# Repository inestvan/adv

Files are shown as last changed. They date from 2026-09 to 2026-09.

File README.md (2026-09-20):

# ADV7280M-CSI2 — CVBS → MIPI CSI-2 декодер для Raspberry Pi 4

Плата на Analog Devices **ADV7280WBCPZ-M** (LFCSP-32): композитный видеосигнал (PAL/NTSC/SECAM, разъём RCA)
преобразуется в поток MIPI CSI-2 (1 лента + клок) и подаётся на разъём камеры Raspberry Pi 4.
В той же заготовке — **отделяемая секция с буфером THS7314**: один вход CVBS раздаётся на декодер и два монитора
(питание секции 5 В от внешнего DC-DC через винтовую клемму).
Работает со штатным overlay ядра Raspberry Pi без правок:

```
dtoverlay=adv728x-m,adv7280m=1
```

Проект сделан в KiCad 9 (`hw/`), плата 4 слоя **42 × 55 мм** (декодер 42 × 32 + паз 2 мм + секция буфера 42 × 21) под стек JLCPCB JLC04161H-7628.
ERC и DRC — 0 ошибок, 0 предупреждений. Все решения и допущения по этапам — в `docs/assumptions.md`,
исходные требования и выжимка из документации — в `docs/requirements.md`.

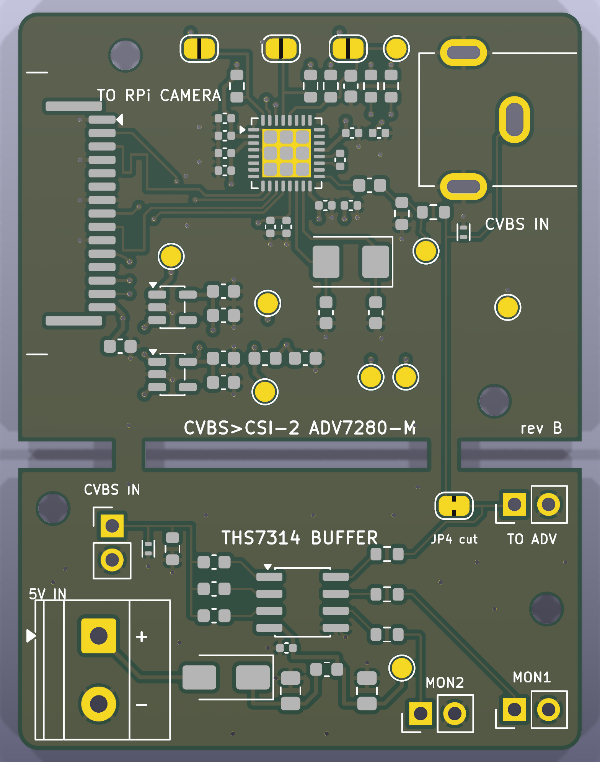
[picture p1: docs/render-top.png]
top


## Состав репозитория

| Путь | Что |
|---|---|
| `hw/adv7280m-csi2.kicad_pro / .kicad_sch / .kicad_pcb` | проект KiCad 9 |
| `hw/lib/` | символы ADV7280WBCPZ-M и THS7314, символы питания, посадочные места FFC (Amphenol SFW15R-1STE1LF), RCA (PSG01546), X1SON |
| `docs/schematic.pdf`, `docs/bom.csv` | схема и BOM с кодами LCSC |
| `docs/render-top.png`, `docs/render-bottom.png`, `docs/layer-*.png` | 3D-рендеры и медь по слоям |
| `docs/datasheets/`, `docs/ref/` | даташит ADV7280 Rev. A, UG-637 Rev. A, AN-1260, THS7314 (SLOS513A), схемы Pi 4 и Camera Module v2.1, overlay/драйвер из ядра Pi |
| `fab/adv7280m-csi2-gerber.zip` | Gerber (RS-274X, Protel-расширения) + Excellon drill + gbrjob со стеком |
| `fab/BOM_JLCPCB.csv`, `fab/CPL_JLCPCB.csv` | BOM и позиции в формате JLCPCB (только то, что собирает JLCPCB) |
| `tools/` | генераторы: `gen_lib.py` → `gen_fp.py` → `gen_sch.py` → `gen_pcb.py` → `route_pcb.py` → `write_pro.py`; `check_nets.py` проверяет нетлист; `fab.sh` делает Gerber/BOM/CPL, `render.sh` — картинки |

Пересборка с нуля:

```
python3 tools/gen_lib.py && python3 tools/gen_fp.py && python3 tools/gen_sch.py && python3 tools/check_nets.py
cd hw && kicad-cli sch export netlist --format kicadxml -o adv7280m-csi2.xml adv7280m-csi2.kicad_sch && cd ..
python3 tools/gen_pcb.py && python3 tools/route_pcb.py && python3 tools/write_pro.py
sh tools/fab.sh          # Gerber, drill, BOM/CPL JLCPCB, schematic.pdf, bom.csv
```

## Схема в двух словах

* **Вход**: RCA J2 → ESD TPD1E10B06 → 22 Ω последовательно, 51 Ω на землю (терминация 73 Ω, делитель 0,7) → 100 нФ → AIN1.
* **Питание**: 3,3 В с пина 15 разъёма камеры. Два LDO AP2112K-1.8: U2 → DVDD+MVDD, U3 → AVDD, PVDD через феррит.
  У каждого вывода питания чипа 100 нФ + 10 нФ.
* **Кварц** 28.63636 МГц (YXC 5032, CL 20 пФ), нагрузочные 27 пФ.
* **MIPI**: D0P/D0N → пины 3/2 разъёма, CLKP/CLKN → пины 9/8; лента 1 не используется. Дифпары 100 Ω (0,18/0,15 мм),
  длины выровнены до 0,04 мм в паре и 0,03 мм между парами.
* **I²C**: SDA/SCL → пины 14/13, подтяжки 4,7 кОм (параллельно подтяжкам Pi). ALSB = 1 → 7-битный адрес **0x21**
  (8-битный 0x42 write / 0x43 read) — ровно то, что ждёт overlay.
* **RESET**: 10 кОм + 4,7 мкФ (τ ≈ 47 мс, низкий уровень ≥ 13 мс), **PWRDWN**: 10 кОм к 3,3 В — чип запускается сам, без участия Pi.

### Секция буфера THS7314 (отделяемая)

* **Вход** J5 (штырьки 2,54 мм: 1 = сигнал, 2 = GND) → терминация 75 Ω, ESD → 3 × 100 нФ → три канала THS7314 (усиление 6 дБ, ФНЧ 8,5 МГц, sync-tip clamp).
* **Выходы** с 75 Ω последовательно (на нагрузке 75 Ω уровень 1 : 1): канал 1 → узел входа декодера (через JP4 и дорожку через перешеек),
  каналы 2 и 3 → J6 «MON1» и J7 «MON2» (штырьки, 1 = сигнал, 2 = GND) на мониторы. J8 «TO ADV» — тот же сигнал канала 1
  для случая, когда секция отломана: соединить кабелем с RCA J2.
* **Питание** J4 (винтовая клемма 5,08 мм, «+» = 5 В, «−» = GND) от внешнего DC-DC 5 В → диод SS14 (защита от переполюсовки)
  → 22 мкФ → феррит → 10 мкФ + 100 нФ. THS7314 работает от 3 до 5 В, LDO не нужен; потребление ≈ 17 мА. Тестовая точка TP9.
* **Декодер питается от Pi** (3,3 В по шлейфу камеры), клемма 5 В его не питает. Pi подключают к тому же 5 В своим кабелем.
* **Разделение**: паз 2 мм и два перешейка 2,5 мм (x = 7…9,5 и 30,5…33 мм). Через перешейки идут только CVBS_IN и земля.
  Перекусить кусачками, края зачистить. После отделения декодер 42 × 32 мм, буфер 42 × 21 мм, у каждого свои отверстия M2.

### Перемычки (паяльные, по умолчанию разомкнуты)

| | Замкнуть, если |
|---|---|
| JP1 `ALSB>GND` | нужен адрес 0x20; тогда в config.txt `dtoverlay=adv728x-m,adv7280m=1,addr=0x20` |
| JP2 `CAM_GPIO>RST` | хотите сбрасывать чип линией CAM_GPIO (пин 11 разъёма). Штатный overlay эту линию не включает, поэтому по умолчанию разомкнуто |
| JP3 `CAM_GPIO>PWRDWN` | хотите усыплять чип линией CAM_GPIO. То же самое: только со своим overlay, где включён регулятор `cam1_reg` |
| JP4 `BUF>ADV` (**замкнута** с завода) | **разрезать**, если платы соединены, а сигнал нужно подать прямо в RCA J2 минуя буфер: иначе выход буфера шунтирует вход |

### Тестовые точки

TP1 3V3 · TP2 1V8D · TP8 1V8A · TP3 SDA · TP4 SCL · TP5 RESET · TP6 GND · TP7 CVBS после терминации (сюда должно приходить ≈0,7 В p-p при 1 В на входе) · TP9 питание THS7314 (≈4,6 В).

## Подключение к Raspberry Pi 4

1. Стандартный 15-жильный шлейф камеры Pi (тот же, что у Camera Module). На плате разъём такой же, как на модуле камеры:
   контакты шлейфа **к плате**, синяя сторона к защёлке. Пин 1 (GND) помечен треугольником, он у верхнего края.
   На Pi 4: контакты шлейфа в сторону HDMI, синяя сторона к Ethernet/USB.
2. Перед первым включением прозвоните: пин 15 шлейфа (3,3 В) ↔ TP1, пин 1 ↔ TP6 (GND).
3. В `/boot/firmware/config.txt` (на старых образах `/boot/config.txt`):

   ```
   camera_auto_detect=0
   dtoverlay=adv728x-m,adv7280m=1
   ```

   Строка `camera_auto_detect=0` отключает автопоиск камер Pi, который иначе может занять I²C и CSI.
4. Перезагрузка и проверка:

   ```
   dmesg | grep -i adv7180          # ожидается: adv7180 10-0021: chip found @ 0x21 ... (шина i2c-10 на Pi 4)
   v4l2-ctl --list-devices          # unicam -> /dev/video0
   v4l2-ctl -d /dev/video0 --get-detected-standard
   v4l2-ctl -d /dev/video0 --set-standard=PAL     # или NTSC
   ```

   Драйвер `adv7180` работает как V4L2 subdevice за `bcm2835-unicam` (в overlay по умолчанию legacy-режим,
   Media Controller выключен). Формат на выходе — 8-битный YUV 4:2:2 (UYVY), 720×576 (PAL) или 720×480 (NTSC), чересстрочный.
5. Захват:

   ```
   v4l2-ctl -d /dev/video0 --set-fmt-video=width=720,height=576,pixelformat=UYVY --stream-mmap --stream-count=100 --stream-to=out.uyvy
   ffmpeg -f v4l2 -input_format uyvy422 -video_size 720x576 -i /dev/video0 -c:v libx264 -preset veryfast out.mkv
   ```

### Вывод на ПК как «карта захвата»

Плата отдаёт только MIPI CSI-2, напрямую к ПК её не подключить. Варианты через Pi 4:

* **UVC-вебкамера по USB-C.** Pi 4 умеет режим USB-устройства: `dtoverlay=dwc2` в config.txt, модуль `libcomposite`,
  и `uvc-gadget` (github.com/raspberrypi/uvc-gadget или kbingham/uvc-gadget с источником V4L2 `/dev/video0`).
  ПК видит обычную вебкамеру 720×576. Не проверялось на этой плате, но это штатный механизм Pi.
* **Поток по сети**: `ffmpeg -f v4l2 -i /dev/video0 ... -f mpegts udp://ПК:5000` или GStreamer/RTSP; на ПК VLC/OBS/ffplay.

## Заказ и сборка на JLCPCB

1. Плата: загрузить `fab/adv7280m-csi2-gerber.zip`. Параметры: 4 слоя, 1,6 мм, стек **JLC04161H-7628**
   (файл `.gbrjob` содержит стек), «Impedance control: yes» (пары 100 Ω дифф, 0,18/0,15 мм), остальное по умолчанию.
   Паз между секциями и перешейки лежат в контуре платы (Edge.Cuts) — это одна плата, опции панелизации/V-cut не нужны.
2. Сборка: Economic (SMT), верхняя сторона. Загрузить `fab/BOM_JLCPCB.csv` и `fab/CPL_JLCPCB.csv`.
   **В предпросмотре обязательно сверить ориентацию** полярных деталей: U2/U3 (SOT-23-5, пин 1 у метки-треугольника),
   D1/D3 (ESD, двунаправленные — ориентация не важна), J1 (FFC: контакты к краю платы, пин 1 сверху), Y1 (кварц — не важна),
   U5 (SOIC-8, пин 1 слева сверху, у метки), D2 (SS14: катодная полоска к C28, т. е. вправо).
   JLCPCB иногда поворачивает корпуса относительно данных KiCad; в предпросмотре это видно по картинке детали.
3. Не собирает JLCPCB (припаять самостоятельно): **U1 ADV7280WBCPZ-M** (нет на складе; фен + трафарет, паста на термопад ≈50 %),
   **J2** RCA-гнездо (любое угловое 3-выводное с штырём 1,3×2,5 и ушками 2,5×1 на 10 мм, например Multicomp PSG01546),
   **J4** винтовая клемма 2 конт. шаг 5,0/5,08 мм (KF301-5.0-2P, LCSC C474881; ставить вводом проводов к кромке),
   **J5–J8** штырьки 1×2 2,54 мм (PZ254V-11-02P, C492401 или любые); перемычки/тестовые точки — это просто площадки.
   THT-сборку у JLCPCB не заказываем — это дешевле, чем доплата за выводной монтаж.
4. Трафарет: заказать вместе с платой («Stencil», верхняя сторона) — он нужен для чипа; паста на термопад уже разбита на 4 окна.

Extended-позиции (по 3 $ за наименование): LDO, кварц, 27 пФ, ESD-диод, FFC-разъём, THS7314. Остальное (21 строка BOM, 48 деталей всего) — Basic.

## Известные особенности

* В каждой дифпаре MIPI линия N делает один переход на нижний слой и обратно (два via 0,45/0,2 мм): порядок P/N на
  разъёме Pi обратен порядку выводов чипа, без перекрёстка это не разводится (см. `docs/assumptions.md`, A3-2).
* 22 Ω вместо 24 Ω в терминации — 24 Ω нет в базовой библиотеке JLCPCB; коэффициент делителя 0,70 вместо 0,68 (+3 % амплитуды), АРУ декодера это компенсирует.
* Пока платы соединены, вход декодера занят буфером: RCA J2 использовать только после разреза JP4.
* Земля Pi и платы замкнута дважды (шлейф камеры и общее питание 5 В). Для CVBS это не критично; при помехах питать Pi и DC-DC от одной точки короткими проводами.
* DC-DC выставить на 5,0 В **до** подключения: абсолютный максимум THS7314 — 5,5 В.

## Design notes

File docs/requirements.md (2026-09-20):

# Требования к плате CVBS → MIPI CSI-2 (ADV7280WBCPZ-M) для Raspberry Pi 4

Этап 0. Выжимка из первоисточников. Всё, что ниже, взято из документов в `docs/datasheets/` и `docs/ref/`;
номера страниц/таблиц указаны по этим файлам.

## 0. Источники

| Файл | Документ | Ревизия | MD5 |
|---|---|---|---|
| `docs/datasheets/ADV7280.pdf` | ADV7280/ADV7280-M Data Sheet | Rev. A (2/2014), 28 стр. | `108880c7c29a0bb6fe3f480b3ebaaed1` |
| `docs/datasheets/UG-637.pdf` | ADV7280/7281/7282/7283 Hardware Reference Manual UG-637 | Rev. A (9/2014), 104 стр. | `9c16c44524c335801548c131bd12a8ec` |
| `docs/datasheets/AN-1260.pdf` | AN-1260 Crystal Design Considerations for Video Decoders… | Rev. 0, 4 стр. | `b3181a87c3ffb049ff7fd0b43f3015a6` |
| `docs/ref/rpi4-reduced-schematics.pdf` | Raspberry Pi 4 Model B Reduced Schematics (datasheets.raspberrypi.com) | 2018 | — |
| `docs/ref/rpi-camera-v2-schematic.pdf` | Raspberry Pi Camera V2.1 schematic (datasheets.raspberrypi.com) | 2.1 | — |
| `docs/ref/adv7282m-overlay.dts`, `adv728x-m-overlay.dts` | raspberrypi/linux, ветка `rpi-6.12.y`, `arch/arm/boot/dts/overlays/` | — | — |
| `docs/ref/adv7180.c`, `adv7180.yaml` | драйвер и DT-binding, та же ветка | — | — |
| `docs/ref/bcm2711-rpi-4-b.dts`, `bcm2711-rpi.dtsi`, `bcm270x.dtsi`, `bcm283x-rpi-*.dtsi` | DTS платы Pi 4 | — | — |
| `docs/ref/overlays-README.txt` | описание параметров overlay | — | — |

PDF ADI получены как архивные копии оригиналов с analog.com (см. `docs/assumptions.md`, A0-1).
Официальная страница пиновки разъёма камеры: raspberrypi.com/documentation/accessories/camera.html (таблица «15-pin CSI connector»).

## 1. ADV7280WBCPZ-M — пиновка (LFCSP-32, 5×5 мм)

Даташит, Figure 7 / Table 10 (стр. 12). Вид сверху, пин 1 в левом верхнем углу, нумерация против часовой стрелки.

| Пин | Имя | Тип | Назначение / подключение на плате |
|---|---|---|---|
| 1, 4 | DGND | GND | земля |
| 2 | DVDDIO | Power | **3,3 В** (2,97–3,63 В) — I/O, I²C, RESET, PWRDWN, ALSB |
| 3 | DVDD | Power | 1,8 В цифра |
| 5 | INTRQ | Out | прерывание — не используется (тестовая точка/NC) |
| 6 | GPO2 | Out | не используется |
| 7 | GPO1 | Out | не используется |
| 8 | GPO0 | Out | не используется |
| 9 | D0P | Out | MIPI data lane 0 + → разъём Pi pin 3 (CAM_DP0) |
| 10 | D0N | Out | MIPI data lane 0 − → разъём Pi pin 2 (CAM_DN0) |
| 11 | CLKP | Out | MIPI clock + → разъём Pi pin 9 (CAM_CP) |
| 12 | CLKN | Out | MIPI clock − → разъём Pi pin 8 (CAM_CN) |
| 13 | MVDD | Power | 1,8 В MIPI Tx |
| 14 | XTALP | Out | кварц 28.63636 МГц (или NC при внешнем генераторе) |
| 15 | XTALN | In | кварц 28.63636 МГц (или вход внешнего генератора 1,8 В) |
| 16 | PVDD | Power | 1,8 В PLL — самый чувствительный к шуму (UG-637 стр. 61) |
| 17 | AIN1 | In | **вход CVBS** (через 24 Ω / 51 Ω / 100 нФ) |
| 18 | AIN2 | In | NC |
| 19 | VREFP | Out | конденсатор VREFP–VREFN, максимально близко к чипу |
| 20 | VREFN | Out | — " — |
| 21 | AVDD | Power | 1,8 В аналог |
| 22–27 | AIN3…AIN8 | In | NC |
| 28 | RESET | In | активный низкий, минимальная длительность **5 мс** (Table 6) |
| 29 | ALSB | In | выбор адреса I²C: 0 → write 0x40, 1 → write 0x42 (Table 15) |
| 30 | SDATA | I/O | I²C SDA |
| 31 | SCLK | In | I²C SCL, ≤ 400 кГц |
| 32 | PWRDWN | In | низкий = power-down |
| EP | EPAD | — | **обязательно на DGND** (тепло, шум, механика) |

Уровни цифровых входов при DVDDIO = 3,3 В: VIH ≥ 2,0 В, VIL ≤ 0,8 В; входы **не 5 В-толерантны** (макс. DVDDIO + 0,3 В).
Ток утечки PWRDWN/ALSB до +50 мкА, RESET ±10 мкА — подтяжки 10 кОм достаточны.

### 1.1 Питание (Table 1, стр. 4; UG-637 Table 89, стр. 62)

| Рельс | Пины | Диапазон | Ток тип. | Ток расчётный (UG-637) |
|---|---|---|---|---|
| DVDDIO | 2 | 2,97–3,63 В | 1,5 мА | 5 мА |
| DVDD | 3 | 1,71–1,89 В | 70 мА | 110 мА |
| AVDD | 21 | 1,71–1,89 В | 47 мА (CVBS) | 100 мА |
| PVDD | 16 | 1,71–1,89 В | 12 мА | 20 мА |
| MVDD | 13 | 1,71–1,89 В | 14 мА | 20 мА |
| **Итого 1,8 В** | | | **≈ 143 мА** | **250 мА** |

Абсолютные максимумы: 1,8 В-рельсы ≤ 2,2 В; DVDDIO ≤ 4 В; |PVDD−DVDD|, |MVDD−DVDD|, |AVDD−DVDD| ≤ 0,9 В (Table 7).
Тепло: θJA = 32,5 °C/W на 4-слойной плате с EP на земле (Table 8).

**Развязка (UG-637 «Power Supply Decoupling», стр. 61, Fig. 44):** у каждого вывода питания — 0,1 мкФ + 10 нФ, в пределах ≈ 0,5 см,
на той же стороне платы, что и чип; ток идёт «плоскость → конденсатор → пин», via под площадкой 100 нФ к плоскости питания.
PVDD — отдельная фильтрация; желательно раздельные регулируемые источники для AVDD/PVDD и DVDD/DVDDIO. Один общий земляной полигон.

### 1.2 Аналоговый вход (даташит Fig. 9, стр. 16; UG-637 Fig. 9, стр. 12)

Разъём → внешний ESD → 24 Ω последовательно → 100 нФ → AIN1; 51 Ω на землю после 24 Ω.
24 + 51 = 75 Ω терминация, делитель 0,68, вход до 1,47 В p-p. Дорожки — минимальной длины, по возможности 75 Ω.
Чип ESD < 2 кВ (HBM) → внешняя защита обязательна (низкоёмкостной TVS/диод).

### 1.3 Кварц (даташит Table 6, стр. 9; AN-1260)

28.63636 МГц, **фундаментальная мода**, стабильность ±50 ppm суммарно (AN-1260 Table 1: калибровка ±30 ppm, температурная ±50 ppm, ESR ≤ 30 Ω, drive 100 мкВт, C0 ≤ 7 пФ).
Нагрузочные конденсаторы по AN-1260: `C1 = C2 = 2·(CL − CS) − CPG`, где CS (паразитная ёмкость платы) 2–3 пФ, CPG (пин–земля) 4–10 пФ.
Пример AN-1260: CL = 30 пФ → 47 пФ. Для SMD-кварца с CL = 18 пФ → 2·(18−3)−4 = 26 → **27 пФ**; CL = 20 пФ → 33 пФ. Значение фиксируется на этапе 1 по выбранному кварцу.

### 1.4 MIPI CSI-2 Tx (даташит Table 3/4, стр. 6–8; UG-637 стр. 55, 61)

* 1 лента данных (D0P/D0N) + клок (CLKP/CLKN). Скорость: **216 Мбит/с** interlaced (по умолчанию), 432 Мбит/с progressive (I2P).
* HS-swing 140–270 мВ, common-mode 150–250 мВ; LP-режим на blanking-интервалах — пары работают и как дифференциальные, и как одиночные.
* UG-637: дорожки **максимально короткие, на той же стороне, что чип**, сплошная опорная (земляная) плоскость в соседнем слое;
  **каждая пара — две слабо связанные 50 Ω одиночные линии** (loosely coupled) → цель: 100 Ω дифф при ~50 Ω SE.
* Внутрипарное выравнивание ≤ 0,1 мм, межпарное ≤ 1 мм (ТЗ); UI при 216 Мбит/с = 4,6 нс — требования нежёсткие, но соблюдаем.
* Без переходных отверстий на MIPI-парах.

### 1.5 I²C (Table 6, Table 15)

≤ 400 кГц. Адреса (8-бит): ALSB = 0 → 0x40/0x41; ALSB = 1 → 0x42/0x43. Подтяжки к 3,3 В на плате Pi уже есть (официальная документация: «SCL and SDA are pulled up to 3.3 V on the Raspberry Pi board»; номинал по reduced-схеме не читается);
на плате — дополнительно 2,2–4,7 кОм (по ТЗ) через перемычки/опционально. Уровень 3,3 В (DVDDIO).

### 1.6 Сброс / Power-down

* RESET: активный низкий, ≥ 5 мс. Достаточно RC-цепи от 3,3 В (10 кОм / 4,7 мкФ → τ = 47 мс: ниже 0,8 В в течение 13 мс после появления 3,3 В; RC 10 мс давал бы только 2,8 мс гарантированного «0») + кнопка/тестовая точка.
* PWRDWN: низкий = power-down; I²C работает и в power-down. Драйвер может использовать `powerdown-gpios`, но overlay Pi их не задаёт (см. §3).

## 2. Разъём камеры Raspberry Pi 4 (J3, 15 конт., шаг 1,0 мм)

Источник: официальная страница raspberrypi.com «Camera → 15-pin CSI connector» + Reduced Schematics Pi 4 (J3 CAMERA).

| Пин | Сигнал Pi 4 | Описание | На нашей плате |
|---|---|---|---|
| 1 | GND | | GND |
| 2 | CAM1_DN0 | D-PHY lane 0 − | D0N (пин 10 чипа) |
| 3 | CAM1_DP0 | D-PHY lane 0 + | D0P (пин 9) |
| 4 | GND | | GND |
| 5 | CAM1_DN1 | D-PHY lane 1 − | NC (1 лента) |
| 6 | CAM1_DP1 | D-PHY lane 1 + | NC |
| 7 | GND | | GND |
| 8 | CAM1_CN | D-PHY clock − | CLKN (пин 12) |
| 9 | CAM1_CP | D-PHY clock + | CLKP (пин 11) |
| 10 | GND | | GND |
| 11 | CAM_GPIO (CAM_IO0) | GPIO-экспандер Pi 4, линия 5 = регулятор `cam1_reg` («Power-Enable»), 3,3 В | опц. перемычки → PWRDWN / RESET |
| 12 | CAM_IO1 | на Pi 4 **не подключён** (на схеме NC) | NC |
| 13 | SCL0 | I²C SCL (3,3 В, подтянут на Pi) | SCLK (пин 31) |
| 14 | SDA0 | I²C SDA | SDATA (пин 30) |
| 15 | 3V3 | питание 3,3 В | вход питания платы |

Особенности Pi 4:
* SCL0/SDA0 разъёма камеры — это шина `i2c0` через мультиплексор `i2c0mux` на **GPIO44/GPIO45** (`bcm283x-rpi-i2c0mux_0_44.dtsi`, канал 1 = `i2c_csi_dsi`), а не GPIO0/1 (те же контроллер, разные пины; GPIO0/1 = ID_SD/ID_SC на 40-pin). Пользователю ничего настраивать не нужно — overlay включает `i2c0if`/`i2c0mux`.
* Разъём CSI на Pi 4 — 2 ленты (`bcm283x-rpi-csi1-2lane.dtsi`), используем одну.
* Нумерация разъёма модуля камеры v2.1 совпадает с J3 Pi (1:1): J1 pin 3 = CSI_D0P, 9 = CLKP, 13 = SCL, 14 = SDA, 15 = 3V3. Наша плата повторяет разъём модуля камеры (см. `assumptions.md` A0-5).
* Ориентация шлейфа на Pi 4: «контакты в сторону от защёлки» (официальная документация).

## 3. Device tree overlay `adv728x-m` (Raspberry Pi kernel `rpi-6.12.y`)

`adv728x-m-overlay.dts` — обёртка над `adv7282m-overlay.dts`; параметр `adv7280m=1` меняет `compatible` на `adi,adv7280-m`.

Что overlay задаёт:
* узел `adv728x@21` на `i2c_csi_dsi`, **`reg = <0x21>`** (7-бит) — т. е. 8-битный адрес записи **0x42 → ALSB = 1**. Параметр `addr=` позволяет переопределить.
* `clock-frequency = <24000000>` (для драйвера не критично), endpoint: `clock-lanes = <0>`, **`data-lanes = <1>`** (одна лента), `link-frequencies = 297 MHz`.
* `csi1` включён, `compatible = "brcm,bcm2835-unicam-legacy"` (если не `media-controller=1`).
* `i2c0if`, `i2c0mux` — `status = "okay"`.

Чего overlay **не задаёт** (проверено по `adv7282m-overlay.dts` и драйверу `adv7180.c`, строки 1517–1531):
* `powerdown-gpios`, `reset-gpios` — драйвер берёт их через `devm_gpiod_get_optional`; при отсутствии — не трогает; сброс выполняет программно (рег. 0x0F[7]).
* регулятор `cam1_reg` (CAM_GPIO) — **не** включается, поэтому уровень пина 11 не гарантирован (скорее всего низкий, т. к. ядро отключает неиспользуемые регуляторы).

**Вывод для схемы:** чип должен быть в рабочем состоянии сразу после подачи 3,3 В без участия Pi:
PWRDWN → подтяжка к 3,3 В; RESET → RC к 3,3 В (≥ 5 мс); ALSB → 3,3 В (адрес 0x21) — с перемычкой на GND (тогда `addr=0x20`).
CAM_GPIO — только через опциональные перемычки. Строка config.txt: `dtoverlay=adv728x-m,adv7280m=1`.

## 4. Печатная плата

* 4 слоя, стек JLCPCB **JLC04161H-7628**: Cu 35 мкм (внешние) / prepreg 7628 0,2104 мм, εr 4,4 / core ~1,065 мм εr 4,6 / prepreg 7628 / Cu; итого 1,6 мм. Слои: L1 сигналы+чип, L2 **сплошная земля**, L3 питание (3,3 В / 1,8 В полигоны), L4 сигналы/земля.
* MIPI 100 Ω дифф на L1 над L2: предварительно **w ≈ 0,18–0,20 мм, s ≈ 0,15 мм** (оценка по микрополосковым формулам; финально — калькулятор JLCPCB на этапе 3). 50 Ω SE ≈ 0,35 мм.
* Аналоговый вход и кварц — вплотную к чипу (AIN1 — пин 17, XTAL — пины 14/15: правая/нижняя стороны корпуса), MIPI — пины 9–12 (нижняя сторона), I²C/RESET/PWRDWN/ALSB — пины 28–32 (верх). Разъём CVBS на одной кромке, FFC — на противоположной; LDO вдали от входа и кварца.
* Термопад 32-LFCSP: массив via на землю (L2).
* Все компоненты с одной стороны (верх); при необходимости 10 нФ у чипа снизу — нежелательно по UG-637 (индуктивность via).

## 5. Инструменты

KiCad 9.0.9 (`kicad-cli`, `pcbnew` Python) установлен; `kicad-cli sch erc` и `kicad-cli pcb drc` работают (проверено на тестовых файлах).

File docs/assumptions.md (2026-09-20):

# Допущения и открытые вопросы

Файл ведётся по ходу всех этапов. Каждое допущение помечено этапом, на котором возникло.
Статус: **OPEN** — ждёт решения заказчика, **ACCEPTED** — подтверждено, **CLOSED** — снято.

## Этап 0

| # | Допущение / вопрос | Статус |
|---|---|---|
| A0-1 | Сайт analog.com недоступен из среды разработки (обрыв TLS/503 на всех запросах). Даташит ADV7280 Rev. A, UG-637 Rev. A и AN-1260 Rev. 0 получены как **архивные копии оригинальных PDF с analog.com через web.archive.org** (`id_`-режим, байт-в-байт оригинал). Контрольные суммы записаны в `docs/requirements.md`. Копии с зеркал дистрибьюторов (Rev. 0 UG-637) удалены как более старые. | ACCEPTED (факт среды) |
| A0-2 | **I²C-адрес.** Overlay `adv7282m` (который включает `adv728x-m`) задаёт `reg = <0x21>` (7-битный адрес) = 8-битный адрес записи **0x42** = по даташиту **ALSB = 1 (лог. «1»)**. ТЗ требует ALSB на GND (0x40 write / 0x20 7-бит). Чтобы строка `dtoverlay=adv728x-m,adv7280m=1` работала **без параметра `addr=`**, ALSB должен быть подтянут к DVDDIO (3,3 В). Предложение: ALSB через перемычку (паяльную) — по умолчанию к 3,3 В (адрес 0x21), опционально на GND (0x20, тогда в config.txt нужно `addr=0x20`). | **DECIDED**: ALSB → 3,3 В через 10 кОм, паяльная перемычка на GND (по умолчанию разомкнута). Выигрыш: `dtoverlay=adv728x-m,adv7280m=1` работает без `addr=`; цена — один резистор и перемычка. |
| A0-3 | **RESET / PWRDWN.** Overlay `adv7282m` **не задаёт** `reset-gpios` / `powerdown-gpios`, а драйвер `adv7180.c` получает их как *optional* (`devm_gpiod_get_optional`) — при их отсутствии драйвер ничего не дёргает и делает только программный сброс по I²C (рег. 0x0F[7]). Overlay также **не включает** регулятор `cam1_reg` (CAM_GPIO, пин 11 разъёма, GPIO-экспандер Pi 4 линия 5), поэтому уровень CAM_GPIO при загрузке с этим overlay не гарантирован (ядро отключает неиспользуемые регуляторы → скорее всего **низкий**). Следствие: чип должен выходить из reset и power-down **аппаратно, без участия Pi**: PWRDWN и RESET — подтяжки к 3,3 В (RESET — RC-цепь ≥ 5 мс по даташиту). Перемычки для подключения CAM_GPIO к PWRDWN (и/или RESET) — опция, по умолчанию разомкнуты. | **DECIDED**: PWRDWN — 10 кОм к 3,3 В; RESET — 10 кОм / 4,7 мкФ к 3,3 В (τ ≈ 47 мс; уровень < 0,8 В держится 13 мс > 5 мс; первоначально было 1 мкФ, изменено на этапе 5 по замечанию внешней проверки) + тестовая точка; две паяльные перемычки CAM_GPIO→PWRDWN и CAM_GPIO→RESET, по умолчанию разомкнуты. Выигрыш: работает со штатным overlay. Что теряем: Pi не может усыпить чип (≈ 250 мВт постоянно); при желании — замкнуть перемычку и включить `cam1_reg` в своём overlay. |
| A0-4 | Питание 1,8 В: типовой ток 1,8 В-рельс ≈ 143 мА (AVDD 47 + DVDD 70 + PVDD 12 + MVDD 14), расчётный по UG-637 табл. 89 — 250 мА. При одном LDO в SOT-23-5 (AP2112K, θJA ≈ 250 °C/W) рассеивание (3,3−1,8)·0,143 = 0,21 Вт → +54 °C типично, до +94 °C при расчётном токе — на грани. UG-637 рекомендует раздельные регуляторы для AVDD/PVDD и цифры. Предложение: **два LDO** — AMS1117-1.8 (SOT-223, JLCPCB Basic) на DVDD+MVDD и малошумящий LDO (AP2112K-1.8 или ME6211C18) на AVDD+PVDD с ферритами. Альтернатива: один LDO в SOT-223 + ферритовые бусины. | **DECIDED**: два одинаковых AP2112K-1.8TRG1 (Diodes, LCSC C176944, SOT-23-5, 600 мА, малошумящий): LDO1 → DVDD+MVDD (≈ 84 мА тип., 0,13 Вт), LDO2 → AVDD+PVDD (≈ 59 мА тип., 0,09 Вт). Выигрыш: тепловой запас ×2 и раздельное аналоговое питание по UG-637; цена +0,17 $ и два конденсатора, без дополнительной платы за extended-деталь (одна и та же позиция). В базовой библиотеке JLCPCB 1,8 В LDO нет вообще (проверено через API JLCPCB), поэтому extended неизбежен. |
| A0-5 | Разъём FFC на плате повторяет **разъём модуля камеры Raspberry Pi** (15 конт., шаг 1,0 мм, нижние контакты, на верхней стороне, у кромки, шлейф выходит наружу), нумерация 1:1 с J3 Pi (1 = GND … 15 = 3V3, подтверждено схемой Camera Module v2.1: J1 pin 3 = D0P, 9 = CLKP, 13 = SCL, 14 = SDA, 15 = 3V3). Предполагается стандартный 15-жильный шлейф камеры Pi (тот, что идёт с Camera Module). Нумерация выводов у разных производителей 15P/1.0 мм разъёмов может отличаться зеркально — **перед первым включением проверить мультиметром: 3,3 В должно приходить на пин 15, GND на пин 1**. | **CLOSED**: на Camera Module v2.1 стоит **Amphenol SFW15R-1STE1LF** (из официальной схемы, J1); он есть у JLCPCB — **C3168538**, 9 395 шт., 0,61 $. Ставим тот же разъём в той же ориентации (верхняя сторона, у кромки, шлейф наружу, контакты к плате) — совместимость со штатным шлейфом получается автоматически, без рассуждений о типе A/B. Проверка мультиметром перед первым включением остаётся хорошей практикой. |
| A0-6 | Используется только лента данных 0 (D0) и клок — `data-lanes = <1>` в overlay. Пины 5/6 (лента 1) разъёма оставляются неподключёнными. | ACCEPTED (следует из overlay) |
| A0-7 | Кварц: UG-637 и даташит не задают значения нагрузочных конденсаторов; используется методика AN-1260 (C = 2·(CL − CS) − CPG). Конкретный кварц выбирается из каталога JLCPCB на этапе 1, C1/C2 считаются под его CL (для CL = 30 пФ по AN-1260 → 47 пФ; для типового SMD-кварца CL = 18–20 пФ → ≈ 27–33 пФ). | ACCEPTED |
| A0-8 | Импеданс MIPI: предварительная оценка по формулам микрополоска для JLC04161H-7628 (h = 0,2104 мм, εr = 4,4): 100 Ω дифф ≈ 0,18–0,20 мм / зазор 0,15 мм. Финальные значения на этапе 3 сверяются с калькулятором JLCPCB. | ACCEPTED |
| A0-9 | KiCad 9.0.9 установлен из PPA `kicad/kicad-9.0-releases`; `kicad-cli sch erc` и `kicad-cli pcb drc` проверены на тестовых файлах. Стандартные библиотеки KiCad 9 (symbols/footprints) установлены. | ACCEPTED |
| A0-10 | **Наличие чипа.** ADV7280WBCPZ-M у JLCPCB — C662261, **склад 0** (цена в каталоге 3,94 $, вероятно устаревшая); все варианты ADV7280x-M на складе 0. Вариант с «WBCPZ-M-RL» (C662262) тоже 0. Для сборки нужно либо consignment (свои чипы, прислать в JLCPCB), либо JLCPCB Global Sourcing / предзаказ, либо самостоятельная пайка. На проектирование не влияет. | **DECIDED**: чип заказчик покупает и паяет сам (фен/трафарет). Следствия для проекта: U1 в BOM/CPL JLCPCB помечается DNP (сборка без чипа), в комплект выходных файлов добавляется трафарет (Gerber paste-слой, площадка термопада с сеткой паяльной пасты ≈ 50 % покрытия), пассивные компоненты 0603 везде, где не требуется близость к пину чипа (развязка у чипа — 0402). |

## Этап 1 (схема)

| # | Допущение / решение | Статус |
|---|---|---|
| A1-1 | Терминация входа: 24 Ω нет в базовой библиотеке JLCPCB (только extended с остатком 1 шт.), поставлено **22 Ω + 51 Ω = 73 Ω** (−2,7 % от 75 Ω, коэффициент делителя 0,70 вместо 0,68, полный диапазон АЦП 1,43 В p-p вместо 1,47 В — для CVBS 1 В p-p запас достаточный). Если нужно ровно 24 Ω — заменить R1 на extended-позицию при заказе. | DECIDED |
| A1-2 | Кварц: YXC YSX530GA 5032 (C112564), CL = 20 пФ, ESR ≤ 40 Ω (у 3225-корпусов HELE ESR 50 Ω, AN-1260 просит ≤ 30 Ω — 5032 ближе всего из складских). Нагрузочные 27 пФ C0G (Fenghua C92670, extended; 27 пФ в Basic нет). | DECIDED |
| A1-3 | ESD на входе: TI TPD1E10B06DPYR (C48260), 12 пФ, ±30 кВ. Nexperia PESD5V0S1BL/S1UL отвергнуты — у них 35 / 150 пФ (проверено по даташитам). 12 пФ при 75 Ω даёт полюс ~180 МГц, для CVBS (6 МГц) незаметно. | DECIDED |
| A1-4 | RCA-гнездо в каталоге JLCPCB отсутствует. Посадочное место сделано по Multicomp Pro PSG01546 (Farnell 3029582): штырь 1,3×2,5 мм, два ушка 2,5×1,0 мм на расстоянии 10 мм, 8,8 мм от переднего края — это стандартный «китайский» угловой RCA 9,7 мм; J2 помечен Assemble=no (пайка вручную). SMA-вариант (J3) удалён по решению заказчика после этапа 3 — вход только RCA. | DECIDED |
| A1-5 | Конденсатор VREFP–VREFN: в даташите/UG-637 номинал не указан, только требование «максимально близко к чипу»; поставлено 100 нФ 0402 (как в референсных схемах ADV7180/ADV7280). | ASSUMED |
| A1-6 | Подтяжки I²C 4,7 кОм на плате параллельно подтяжкам Pi; суммарно ≥ 1,3 кОм → ток стока ≤ 2,5 мА, в норме I²C. | DECIDED |
| A1-7 | Подтяжки RESET/PWRDWN/ALSB 10 кОм (утечка ≤ 50 мкА → падение ≤ 0,5 В, VIH = 2,0 В соблюдён). RC на RESET 10 кОм/4,7 мкФ (τ = 47 мс; RESET < 0,8 В до 13 мс, > 2 В с 44 мс; минимум по даташиту 5 мс низкого уровня). Исходные 1 мкФ (τ = 10 мс) давали лишь 2,8 мс гарантированного «0». Даташит также допускает упрощённый запуск: все питания и RESET одновременно + программный сброс, что и делает драйвер adv7180. | DECIDED (изменено на этапе 5) |
| A1-8 | Неиспользуемые выводы AIN2–AIN8, GPO0–2, INTRQ оставлены неподключёнными (даташит не требует подтяжек); лента 1 разъёма (пины 5, 6) и пин 12 — NC. | DECIDED |
| A1-9 | Поле `Assemble = no` у U1 и J2 — признак «не собирать на JLCPCB» для BOM/CPL этапа 4. Тестовые точки — SMD-площадки Ø1,5 мм (без сверления). | DECIDED |

## Этап 2 (размещение)

| # | Решение | Статус |
|---|---|---|
| A2-1 | Плата **42 × 32 мм**, 4 слоя, стек JLC04161H-7628 (записан в файл платы): F.Cu 35 мкм / prepreg 7628 0,2104 мм εr 4,4 / In1 (GND) / core 1,065 мм / In2 (PWR) / prepreg 7628 / B.Cu. Углы R1,5. Размер оставлен с запасом под трассировку; после этапа 3 можно ужать примерно до 40 × 30. | DECIDED |
| A2-2 | Разъём FFC J1 на **левой** кромке, шлейф выходит влево; вход CVBS (RCA J2 + SMA J3) на **правой** кромке. Ориентация FFC повторяет модуль камеры: контакты к плате, при взгляде сверху и шлейфе «на себя» пин 1 слева → на левой кромке пин 1 **сверху** (метка-треугольник на шелкографии), 3V3 (пин 15) снизу. | DECIDED |
| A2-3 | U1 повёрнут на 0°: пины MIPI 9–12 на нижней кромке корпуса слева (ближе к FFC), кварц 14/15 на той же кромке справа — кварц стоит справа-снизу от чипа, дифпары уходят влево; AIN1 (пин 17) на правой стороне — входная цепь и разъёмы справа; I²C/RESET/ALSB/PWRDWN (28–32) на верхней кромке — подтяжки и перемычки JP1–JP3 вдоль верхней кромки платы. | DECIDED |
| A2-4 | LDO U2/U3 в левом нижнем углу, рядом с пином 15 (3V3) разъёма и максимально далеко от входа и кварца. Развязка 100 нФ/10 нФ у каждого вывода питания на верхней стороне, все компоненты сверху. | DECIDED |
| A2-5 | Позиционные обозначения перенесены на слой F.Fab (на шелкографии остались только надписи разъёмов и имя платы) — иначе на плотной 0402-развязке DRC даёт наложение шелкографии на площадки. | DECIDED |
| A2-6 | Корпус RCA-гнезда 12 мм в глубину занимает x 30–42 — под ним нет компонентов, только дорожки. SMA (J3) удалён после этапа 3; правая нижняя часть платы свободна под будущий каскад THS7314. | DECIDED |
| A2-7 | Два отверстия M2 по диагонали: (8; 3,2) и (35,5; 29). | DECIDED |

## Этап 3 (трассировка)

| # | Решение | Статус |
|---|---|---|
| A3-1 | **Импеданс MIPI.** Стек JLC04161H-7628: h = 0,2104 мм до земли In1, εr 4,4, Cu 35 мкм. Расчёт по формулам Хаммерстада–Йенсена (микрополосок): одиночная линия 0,18 мм ≈ 69 Ω; пара 0,18 / зазор 0,15 мм ≈ 104 Ω без маски, ≈ 100 Ω с паяльной маской. Это соответствует рекомендации UG-637 «две слабосвязанные 50 Ω линии». Итог: **ширина 0,18 мм, зазор 0,15 мм**, класс цепей MIPI в проекте. При заказе с контролем импеданса JLCPCB сам подгонит ширину под 100 Ω. | DECIDED |
| A3-2 | **Перекрёстные переходы в дифпарах — неизбежны.** На чипе порядок выводов на кромке: D0P, D0N, CLKP, CLKN (P левее N). На разъёме Pi (нумерация 1:1 с модулем камеры): N-контакт выше P-контакта в обеих парах (пин 2 = D0N, 3 = D0P; 8 = CLKN, 9 = CLKP). Входя в контакты разъёма слева-направо, P должен быть сверху, а трассировка от чипа даёт P снизу; на одном слое без пересечения это невозможно (топологически, любой поворот не меняет порядок), обход под площадками разъёма тоже невозможен (площадки с шагом 1 мм). Поэтому в каждой паре линия N делает один переход на B.Cu под линией P и возвращается: **2 via 0,45/0,2 мм на пару**, остальное без переходных. Драйвер Pi не умеет инвертировать полярность лент, программно это не решить. | DECIDED |
| A3-3 | **Длины** (медь + 1,6 мм на каждый via): D0P 18,61 / D0N 18,65 мм (расхождение 0,04); CLKP 18,61 / CLKN 18,60 (0,01); между парами 0,03 мм. Выравнивание змейками на P-линиях, все на верхнем слое, под парами сплошная земля In1 без разрывов. | DECIDED |
| A3-4 | **Питание**: полигоны на In2 — +3V3 (левая колонка и полоса под подтяжками), +1V8D (центр), +1V8A (правый верх, коридор справа, нижняя полоса). PVDD ведётся дорожкой 0,4 мм по B.Cu от феррита к конденсаторам у вывода 16 (полигон был бы слишком узок). Все дорожки питания на верхнем слое 0,3–0,4 мм. | DECIDED |
| A3-5 | **Земля**: сплошной полигон In1, заливка GND на F.Cu и B.Cu, термопад U1 — 9 via 0,5/0,3 с шагом 1 мм. Выводы DGND 1 и 4 заведены короткими дорожками прямо на термопад (между соседними площадками места под via нет). У каждого GND-вывода конденсатора — свой via. | DECIDED |
| A3-6 | **Аналог**: цепи CVBS 0,15 мм (≈ 74 Ω по тому же расчёту), кварц — дорожки ≤ 6 мм, вокруг заливка земли; I²C, CAM_GPIO — по B.Cu, пересекают MIPI только через плоскость земли. | DECIDED |
| A3-7 | DRC (kicad-cli, все уровни, с проверкой соответствия схеме): **0 ошибок, 0 предупреждений, 0 неподключённых**. Правила: зазор 0,2 мм (MIPI внутри пары 0,15), дорожка ≥ 0,127, via ≥ 0,45/0,2, до края ≥ 0,3 — в пределах возможностей JLCPCB для 4 слоёв. | DECIDED |
| A3-8 | Размер платы оставлен 42 × 32 мм: справа-снизу есть свободное место, но именно там заказчик планирует стыковать отделяемый каскад THS7314 (обсуждается после этапа 4). | CLOSED: каскад THS7314 добавлен на этапе 5 как отделяемая секция справа от основной платы. |

## Этап 4 (выходные файлы)

| # | Решение | Статус |
|---|---|---|
| A4-1 | Gerber: RS-274X без X2-атрибутов, Protel-расширения, маска вычтена из шелкографии, внутренние слои переименованы в `In1_Cu.g2` / `In2_Cu.g3` (соглашение JLCPCB для KiCad), `.gbrjob` со стеком JLC04161H-7628. Drill: Excellon, мм, PTH и NPTH раздельно, карты в Gerber X2. | DECIDED |
| A4-2 | BOM/CPL JLCPCB содержат только собираемые позиции (34 компонента, 15 строк BOM). Исключены: U1 (нет на складе, ручная пайка), J2 (нет в каталоге), JP1–JP3, TP1–TP8, H1–H2 (нет деталей). Углы в CPL — как в KiCad, нормированы в 0–360; ориентацию U2/U3/J1 проверить в предпросмотре JLCPCB. | DECIDED |
| A4-3 | Инструкции по UVC-режиму (Pi как вебкамера) и сетевому стриму в README даны как штатные механизмы Raspberry Pi OS, на этой плате не проверялись. | ASSUMED |

## Этап 5 (буферный каскад THS7314, отделяемая секция)

| # | Решение | Статус |
|---|---|---|
| A5-1 | **Питание THS7314 — напрямую от 5 В** модуля DC-DC (после защитного диода ≈ 4,6 В), без LDO. По SLOS513A чип работает от 3 до 5 В; при 4,6 В размах выхода 4,5 В тип. в 75 Ω даёт запас > 2 В для видео 2 В p-p (после ×2) + 0,29 В смещения клампа. При 3,3 В запас был бы ~0,7 В (размах 3,0 В) — работает, но хуже по перегрузке. Ток покоя 17 мА. Пульсации DC-DC давятся FB2 (BLM18PG121SN1D) + 10 мкФ + 100 нФ у вывода 4; PSRR чипа 55 дБ. | DECIDED |
| A5-2 | Защита от переполюсовки — диод Шоттки **SS14** (C2480, Basic) последовательно в +5 В: падение ≈ 0,4 В при 20 мА, при 17 мА нагрузки P-MOSFET не оправдан. Объёмный конденсатор 22 мкФ 0805 (C45783, Basic) после диода — по рекомендации даташита (22–100 мкФ на линии питания). | DECIDED |
| A5-3 | Входная цепь буфера (SLOS513A, Fig. 33/34): терминация **75 Ω** (C4275, Basic) на входном штырьковом разъёме J5, ESD TPD1E10B06 (D3, та же позиция, что D1), **три отдельных 100 нФ** (C23–C25, 0603 50 В X7R, C14663) — по одному на каждый вход, т.к. у каждого входа свой клампер (sync-tip clamp / DC-restore); общий конденсатор на три входа недопустим. Опциональный 10–47 пФ параллельно терминации не ставится. | DECIDED |
| A5-4 | Выходы: усиление 6 дБ (×2), на каждом выходе **75 Ω последовательно** (back-termination) → на нагрузке 75 Ω итоговое усиление 1. CH1 → узел CVBS_IN основной платы (через паяльную перемычку **JP4, по умолчанию замкнута**; далее штатная цепь D1/R1/R2/C1 без изменений). CH2, CH3 → штырьковые разъёмы J6, J7 (2 контакта: сигнал, GND) на мониторы. J8 — штырьковый выход CH1 для использования после отделения секции (кабель на RCA J2). Пока платы соединены и нужно подать сигнал прямо на J2 — перерезать JP4 (иначе выход буфера шунтирует вход). | DECIDED |
| A5-5 | **Способ разделения** (уточняется на этапе 5б): фрезерованный паз шириной 2 мм между секциями и **два перешейка** (без mouse-bites), через которые проходят единственные две связи — CVBS_IN и GND (плюс земляной полигон In1). Отламывается/перекусывается кусачками. V-cut отвергнут: JLCPCB требует ≥ 0,4 мм от линии V-cut до меди, т.е. дорожку через V-cut провести нельзя, а 0 Ω-перемычка поверх V-cut ломается при разделении и вызывает вопросы DFM. Заказ — как одна обычная плата, без опций панелизации. Реализовано на этапе 5б: паз 2 мм (y = 32…34 мм) на всю ширину платы, перешейки 2,5 мм при x = 7…9,5 (только земля) и x = 30,5…33 мм (CVBS_IN + земля). | DECIDED |
| A5-6 | Разъёмы секции (все **Assemble = no**, ручная пайка, THT-сборка JLCPCB не заказывается): винтовая клемма **KF301-5.0-2P** (C474881, шаг 5,0 мм) на посадочном месте Phoenix MKDS-1,5/2-5.08 (разница шага 0,08 мм = 0,04 мм на контакт, отверстия Ø1,3 мм — влезает); штырьковые разъёмы 1×2 2,54 мм **PZ254V-11-02P** (C492401) для J5–J8. Пин 1 каждого разъёма — сигнал, пин 2 — GND (на шелкографии будет помечено). | DECIDED |
| A5-7 | Земля: буферная секция и декодер имеют общую землю через перешеек; Pi питается от того же модуля 5 В своим кабелем, поэтому земля Pi ↔ плата замкнута и через шлейф камеры, и через питание (земляная петля через модуль; для CVBS с терминацией 75 Ω это не критично, при помехах — питать Pi и модуль от одной точки короткими проводами). После отделения секции общая земля — через экран кабеля J8 → J2. | ASSUMED |
| A5-8 | THS7314DR — C882751, extended, 4 442 шт., 0,68 $ (Basic-аналогов трёхканального видеобуфера у JLCPCB нет). Схема сведена на одном листе (формат увеличен до A2), ревизия B; ERC — 0 нарушений, автопроверка цепей (`tools/check_nets.py`) расширена на секцию буфера. | DECIDED |
| A5-9 | **Секция буфера размещена снизу** от платы декодера (плата стала **42 × 55 мм**), а не справа: на правой кромке стоит RCA-гнездо J2, и штекер должен входить свободно и после стыковки. Расположение: J5 (вход CVBS, штырьки) — левый верх секции; J4 (клемма 5 В) — левый нижний угол, провода выходят через нижнюю кромку; J6/J7 (мониторы) — нижняя кромка справа; J8 (выход на декодер) и JP4 — правый верх, у перешейка с дорожкой CVBS_IN; U5 в центре, входные конденсаторы слева, выходные 75 Ω справа; цепь питания D2 → C28 → FB2 → C27 → C26 вдоль нижнего края к выводу 4. Отверстия H3/H4 на секции — для крепления после отделения. Клемма симметрична по выводам: при ручной пайке ставить стороной ввода проводов к кромке (посадочное место оставляет 5,75 мм запаса в обе стороны). | DECIDED |
| A5-10 | **Разводка секции (этап 5в).** CVBS_IN идёт одной дорожкой 0,15 мм от узла D1/R1 вертикально (x = 31,9) через правый перешеек к JP4; CVBS_BUF заходит на JP4 справа (мостик перемычки — net-tie, чужие дорожки его касаться не должны). Видеоцепи 0,15 мм, питание 0,3 мм. Земля: сплошной In1 через оба перешейка, заливки F/B, дополнительно зона GND на In2 под секцией, 22 сшивающих/возвратных via. DRC (kicad-cli, все уровни): 0 нарушений, 0 неподключённых. | DECIDED |
| A5-11 | **Возвратный путь MIPI** (по замечанию внешней проверки к A3-2): зона +3V3 на In2 расширена до x = 13,9 мм в полосе y = 11,6…16,5, зона +1V8D соответственно вырезана, так что оба коротких участка N-линий на B.Cu (D0N x = 11,8…13,2; CLKN x = 9,0…10,1) лежат над одной сплошной опорной плоскостью без стыка; рядом с переходами D0N добавлены два земляных via (12,5; 12,2) и (12,6; 15,9). Длины пар не изменились (расхождение ≤ 0,04 мм). | DECIDED |

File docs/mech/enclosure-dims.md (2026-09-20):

# Размеры платы для корпуса (rev B)

Система координат: вид сверху (сторона компонентов), начало — левый верхний угол платы, X вправо, Y вниз, мм.
В DXF (`board-outline.dxf`, `board-top-fab.dxf`) ось Y направлена вверх (стандарт CAD): Y_dxf = −Y_таблицы.
`board.step` — контур платы и корпуса компонентов (стандартные 3D-модели KiCad в среде сборки отсутствовали,
поэтому в STEP только плата; высоты компонентов — в таблицах ниже).

## Плата

| | мм |
|---|---|
| Габарит | 42,0 × 55,0, толщина 1,6, углы R1,5 |
| Секция декодера | Y = 0…32 |
| Паз разделения | Y = 32…34, во всю ширину; перешейки X = 7,0…9,5 и 30,5…33,0 |
| Секция буфера | Y = 34…55 |
| После отделения | декодер 42 × 32, буфер 42 × 21 (кромки у паза после зачистки перешейков — плоские) |

## Крепёжные отверстия Ø 2,2 (M2, без металлизации; вокруг ≥ Ø 5 свободно)

| | X | Y |
|---|---|---|
| H1 | 8,0 | 3,2 |
| H2 | 35,5 | 29,0 |
| H3 | 2,6 | 37,0 |
| H4 | 39,4 | 44,5 |

Стойки под платой: ≥ 3,5 мм (снизу торчат выводы клеммы и штырьков ≈ 3 мм и пайка). Снизу компонентов нет.

## Что выходит через стенки корпуса

| Элемент | Стенка | Положение | Проём в стенке (рекомендация) |
|---|---|---|---|
| J1 шлейф камеры (FFC 15 конт., 1,0 мм) | левая (X = 0) | центр Y = 15,0; корпус разъёма Y = 6,1…23,9, X = 0…5,5; высота 3,0 (замок открыт ≈ 5,5, нужно место сверху для пальца) | щель 18 × 1,5 у самой платы (шлейф 16 мм шириной, 0,3 мм толщиной), плюс доступ к замку сверху |
| J2 RCA-гнездо | правая (X = 42) | штырь (37,0; 8,0); корпус на плате X = 30…42, Y = 3…13; гнездо выступает за кромку ≈ 9,5 (до X ≈ 51,5) | отверстие Ø 10, центр Y = 8,0, высота оси над платой ≈ 6 (проверить по своему гнезду) |
| J4 клемма 5 В | нижняя (Y = 55) | выводы (6,0; 46,5) и (6,0; 51,58); корпус X = 0,9…11,8, Y = 43,4…54,7; высота ≈ 9–10 | проём 12 × 7 (низ у платы), провода входят снизу; сверху нужен доступ отвёртки к винтам (или крышка съёмная) |
| J6 MON1, J7 MON2 (штырьки 1×2) | нижняя | J7 (30,0; 52,3)+(32,54; 52,3); J6 (37,0; 52,0)+(39,54; 52,0); высота ≈ 8,5 | вертикальные штыри — кабель уходит вверх, в нижней стенке проём не нужен; либо окно в крышке |
| J5 CVBS IN (штырьки 1×2) | левая/верх | (7,0; 38,3) и (7,0; 40,84); высота ≈ 8,5 | окно в крышке над штырями |
| J8 TO ADV (штырьки 1×2) | — | (37,0; 36,7) и (39,54; 36,7); нужен только при отделённой секции | окно в крышке |

Если хочется горизонтальные выводы, штырьки J5–J8 можно впаять угловые (тот же шаг 2,54) — тогда проёмы 6 × 3 в стенке у платы.

## Высота компонентов над платой (верх)

| Зона | мм |
|---|---|
| RCA J2 | ≈ 10 (самый высокий на декодере) |
| Клемма J4 | ≈ 9–10 |
| Штырьки J5–J8 | 8,5 (пластик 2,5 + штырь 6) |
| FFC J1 | 3,0 (замок открыт ≈ 5,5) |
| Кварц Y1, LDO, SOIC THS7314 | ≤ 1,6 |
| Остальные SMD | ≤ 1,0 |

Итого внутренняя высота корпуса над платой: ≥ 11 мм (без учёта воткнутых кабелей), плюс стойки 3,5 снизу → внутренняя высота ≈ 16 мм при толщине платы 1,6.

## Прочее

* Тестовые точки TP1–TP9 и перемычки JP1–JP4 — площадки на верхней стороне, при желании окна в крышке: JP1–JP3 вдоль верхней кромки (Y = 2,7, X = 13,5 / 19,6 / 24,6), JP4 (32,5; 36,8).
* Чип U1 (20,0; 10,5) греется слабо (≈ 0,3 Вт), вентиляция не нужна; THS7314 ≈ 0,1 Вт.
* Шлейф камеры входит в J1 контактами вниз (к плате); минимальный радиус изгиба FFC ≈ 3 мм.

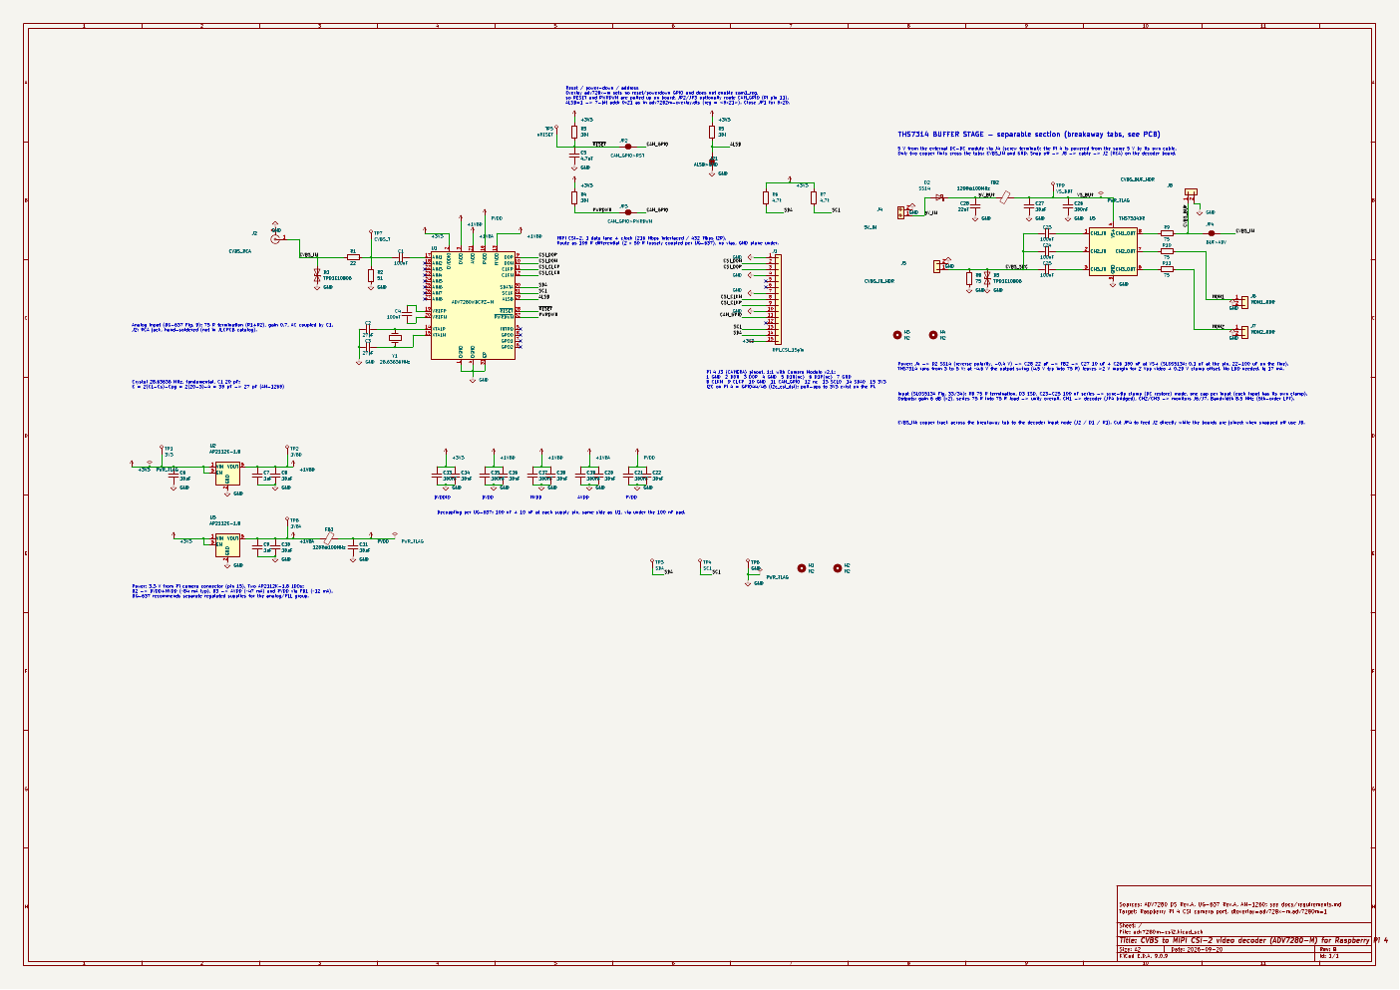
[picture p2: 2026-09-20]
docs/schematic-1.png

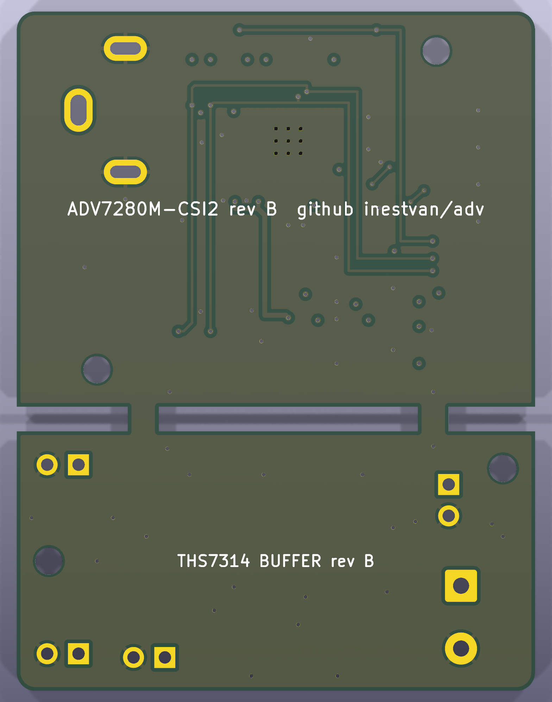
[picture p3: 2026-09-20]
docs/render-bottom.png

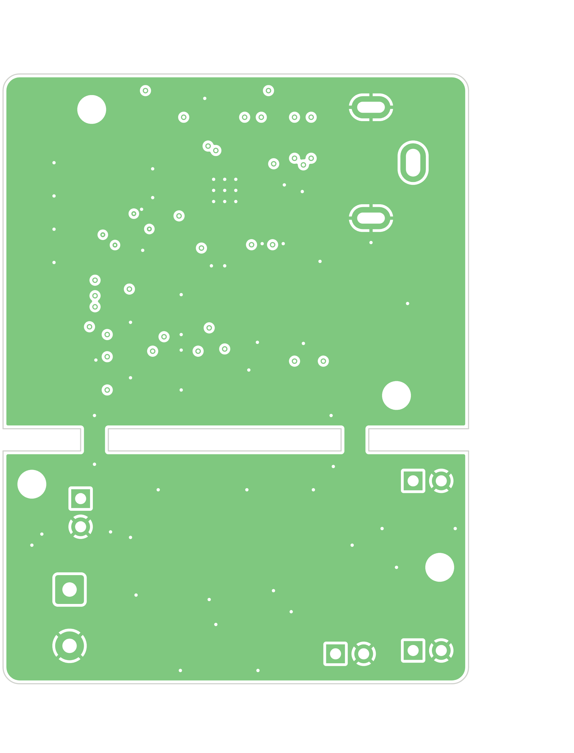
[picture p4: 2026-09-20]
docs/layer-in1-gnd.png

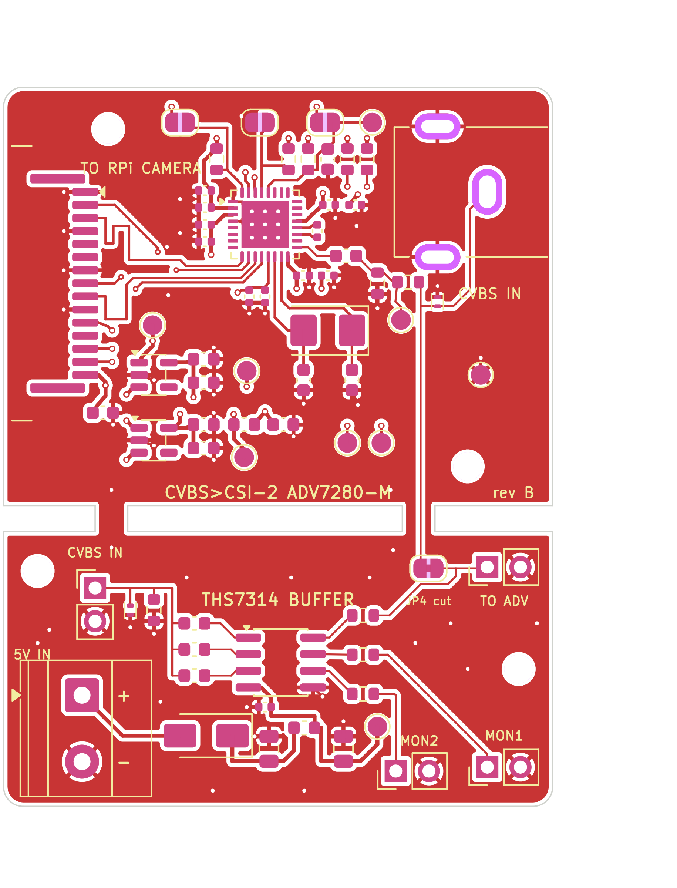
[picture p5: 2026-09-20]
docs/layer-top.png

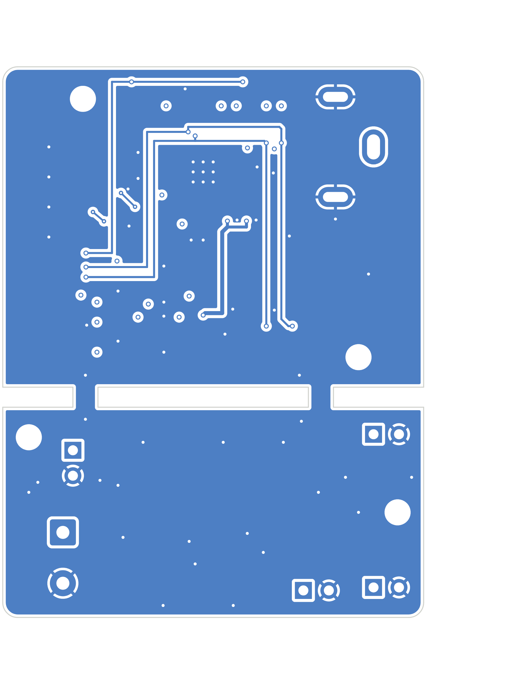
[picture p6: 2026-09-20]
docs/layer-bottom.png

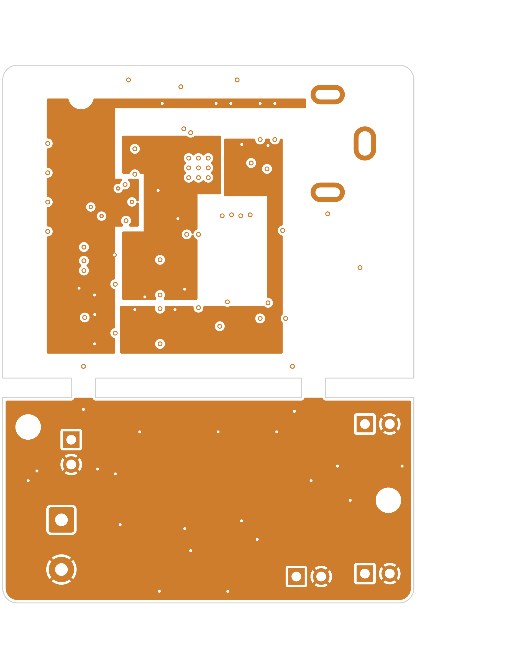
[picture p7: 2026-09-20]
docs/layer-in2-pwr.png

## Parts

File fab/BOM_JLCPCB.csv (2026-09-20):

Comment | Designator | Footprint | LCSC Part #
100nF | C1,C23,C24,C25 | C_0603_1608Metric | C14663
27pF | C2,C3 | C_0603_1608Metric | C92670
100nF | C4,C13,C15,C17,C19,C21,C26 | C_0402_1005Metric | C1525
4.7uF | C5 | C_0603_1608Metric | C19666
10uF | C6,C8,C10,C11 | C_0603_1608Metric | C19702
1uF | C7,C9 | C_0603_1608Metric | C15849
10nF | C14,C16,C18,C20,C22 | C_0402_1005Metric | C15195
10uF | C27 | C_0805_2012Metric | C15850
22uF | C28 | C_0805_2012Metric | C45783
TPD1E10B06 | D1,D3 | TI_X1SON-2_DPY0002A_1.0x0.6mm | C48260
SS14 | D2 | D_SMA | C2480
120R@100MHz | FB1,FB2 | L_0603_1608Metric | C14709
RPi_CSI_15pin | J1 | Amphenol_SFW15R-1STE1LF | C3168538
22 | R1 | R_0603_1608Metric | C23345
51 | R2 | R_0603_1608Metric | C23197
10k | R3,R4,R5 | R_0603_1608Metric | C25804
4.7k | R6,R7 | R_0603_1608Metric | C23162
75 | R8,R9,R10,R11 | R_0603_1608Metric | C4275
AP2112K-1.8 | U2,U3 | SOT-23-5 | C176944
THS7314DR | U5 | SOIC-8_3.9x4.9mm_P1.27mm | C882751
28.63636MHz | Y1 | Crystal_SMD_5032-2Pin_5.0x3.2mm | C112564

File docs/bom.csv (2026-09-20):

Reference | Value | Footprint | LCSC | MPN | Assemble | Description | Qty
C1,C23-C25 | 100nF | Capacitor_SMD:C_0603_1608Metric | C14663 |  |  | AC coupling, 50 V X7R 0603,CH1 input coupling, sync-tip clamp mode (SLOS513A Fig. 34), 50 V X7R,CH2 input coupling, sync-tip clamp mode (SLOS513A Fig. 34), 50 V X7R,CH3 input coupling, sync-tip clamp mode (SLOS513A Fig. 34), 50 V X7R | 4
C2,C3 | 27pF | Capacitor_SMD:C_0603_1608Metric | C92670 |  |  | Crystal load, C0G | 2
C4,C13,C15,C17,C19,C21,C26 | 100nF | Capacitor_SMD:C_0402_1005Metric | C1525 |  |  | AVDD decoupling, at pin,DVDD decoupling, at pin,DVDDIO decoupling, at pin,MVDD decoupling, at pin,PVDD decoupling, at pin,VREFP-VREFN, close to U1,VS+ decoupling at pin 4 (SLOS513A: 0.1 uF as close as possible) | 7
C5 | 4.7uF | Capacitor_SMD:C_0603_1608Metric | C19666 |  |  | RESET RC, tau = 47 ms: low (<0.8 V) for 13 ms after 3V3 (>5 ms min), high (>2 V) at 44 ms | 1
C6,C8,C10,C11 | 10uF | Capacitor_SMD:C_0603_1608Metric | C19702 |  |  | 3V3 input bulk, 10 V X5R,LDO output bulk,PVDD bulk after ferrite | 4
C7,C9 | 1uF | Capacitor_SMD:C_0603_1608Metric | C15849 |  |  | LDO output, X7R | 2
C14,C16,C18,C20,C22 | 10nF | Capacitor_SMD:C_0402_1005Metric | C15195 |  |  | AVDD decoupling, at pin,DVDD decoupling, at pin,DVDDIO decoupling, at pin,MVDD decoupling, at pin,PVDD decoupling, at pin | 5
C27 | 10uF | Capacitor_SMD:C_0805_2012Metric | C15850 |  |  | VS+ bulk, 25 V X5R 0805 | 1
C28 | 22uF | Capacitor_SMD:C_0805_2012Metric | C45783 |  |  | Bulk after D2, 25 V X5R 0805 (SLOS513A: 22-100 uF on supply) | 1
D1,D3 | TPD1E10B06 | adv-parts:TI_X1SON-2_DPY0002A_1.0x0.6mm | C48260 |  |  | ESD TVS on buffer input, 12 pF,ESD TVS, 12 pF, bidirectional | 2
D2 | SS14 | Diode_SMD:D_SMA | C2480 |  |  | Reverse-polarity protection, 1 A, Vf ~0.4 V at 20 mA | 1
FB1,FB2 | 120R@100MHz | Inductor_SMD:L_0603_1608Metric | C14709 | BLM18PG121SN1D |  | BLM18PG121SN1D, DC-DC ripple filter,BLM18PG121SN1D, PVDD filter | 2
J1 | RPi_CSI_15pin | adv-parts:Amphenol_SFW15R-1STE1LF | C3168538 | SFW15R-1STE1LF |  | FFC 15 pos 1.0 mm bottom contact (Amphenol SFW15R-1STE1LF, same as Pi Camera Module) | 1
J2 | CVBS_RCA | adv-parts:RCA_Multicomp_PSG01546_Horizontal |  | PSG01546 or equivalent | no | RCA jack, hand-soldered (not stocked by JLCPCB) | 1
J4 | 5V_IN | TerminalBlock_Phoenix:TerminalBlock_Phoenix_MKDS-1,5-2-5.08_1x02_P5.08mm_Horizontal | C474881 | KF301-5.0-2P | no | Screw terminal 5.08 mm, 5 V from external DC-DC module (hand-soldered) | 1
J5 | CVBS_IN_HDR | Connector_PinHeader_2.54mm:PinHeader_1x02_P2.54mm_Vertical | C492401 | PZ254V-11-02P | no | CVBS source input, 2.54 mm pin header (1 = signal, 2 = GND), hand-soldered | 1
J6 | MON1_HDR | Connector_PinHeader_2.54mm:PinHeader_1x02_P2.54mm_Vertical | C492401 | PZ254V-11-02P | no | CVBS to monitor 1, 2.54 mm pin header (1 = signal, 2 = GND), hand-soldered | 1
J7 | MON2_HDR | Connector_PinHeader_2.54mm:PinHeader_1x02_P2.54mm_Vertical | C492401 | PZ254V-11-02P | no | CVBS to monitor 2, 2.54 mm pin header (1 = signal, 2 = GND), hand-soldered | 1
J8 | CVBS_BUF_HDR | Connector_PinHeader_2.54mm:PinHeader_1x02_P2.54mm_Vertical | C492401 | PZ254V-11-02P | no | Buffered CVBS to decoder when the section is snapped off (1 = signal, 2 = GND), hand-soldered | 1
JP1 | ALSB>GND | Jumper:SolderJumper-2_P1.3mm_Open_RoundedPad1.0x1.5mm |  |  |  | Close for I2C addr 0x20 (needs dtoverlay addr=0x20) | 1
JP2 | CAM_GPIO>RST | Jumper:SolderJumper-2_P1.3mm_Open_RoundedPad1.0x1.5mm |  |  |  | Open by default: connects CAM_GPIO to RESET | 1
JP3 | CAM_GPIO>PWRDWN | Jumper:SolderJumper-2_P1.3mm_Open_RoundedPad1.0x1.5mm |  |  |  | Open by default: connects CAM_GPIO to PWRDWN | 1
JP4 | BUF>ADV | Jumper:SolderJumper-2_P1.3mm_Bridged_RoundedPad1.0x1.5mm |  |  |  | Bridged by default: buffer CH1 -> decoder input node. Cut to use J2 while boards are joined | 1
R1 | 22 | Resistor_SMD:R_0603_1608Metric | C23345 |  |  | Series termination (24 R in UG-637 Fig. 9; 22 R = nearest JLCPCB Basic) | 1
R2 | 51 | Resistor_SMD:R_0603_1608Metric | C23197 |  |  | Shunt termination, 22+51 = 73 R | 1
R3-R5 | 10k | Resistor_SMD:R_0603_1608Metric | C25804 |  |  | ALSB pull-up: I2C addr 0x21 (write 0x42) = overlay default,PWRDWN pull-up (chip enabled by default),RESET pull-up | 3
R6,R7 | 4.7k | Resistor_SMD:R_0603_1608Metric | C23162 |  |  | SCL pull-up (in parallel with Pi pull-up),SDA pull-up (in parallel with Pi pull-up) | 2
R8-R11 | 75 | Resistor_SMD:R_0603_1608Metric | C4275 |  |  | CH1 back-termination -> decoder,CH2 back-termination -> monitor 1,CH3 back-termination -> monitor 2,Input termination 75 R | 4
TP1 | 3V3 | TestPoint:TestPoint_Pad_D1.5mm |  |  |  | 3.3 V test point | 1
TP2 | 1V8D | TestPoint:TestPoint_Pad_D1.5mm |  |  |  | 1.8 V digital test point | 1
TP3 | SDA | TestPoint:TestPoint_Pad_D1.5mm |  |  |  | SDA test point | 1
TP4 | SCL | TestPoint:TestPoint_Pad_D1.5mm |  |  |  | SCL test point | 1
TP5 | nRESET | TestPoint:TestPoint_Pad_D1.5mm |  |  |  | RESET test point | 1
TP6 | GND | TestPoint:TestPoint_Pad_D1.5mm |  |  |  | GND test point | 1
TP7 | CVBS_T | TestPoint:TestPoint_Pad_D1.5mm |  |  |  | CVBS after termination | 1
TP8 | 1V8A | TestPoint:TestPoint_Pad_D1.5mm |  |  |  | 1.8 V analog test point | 1
TP9 | VS_BUF | TestPoint:TestPoint_Pad_D1.5mm |  |  |  | Buffer supply test point | 1
U1 | ADV7280WBCPZ-M | Package_DFN_QFN:QFN-32-1EP_5x5mm_P0.5mm_EP3.6x3.6mm | C662261 | ADV7280WBCPZ-M | no | SDTV video decoder, MIPI CSI-2 output, LFCSP-32 (hand-soldered by owner, not by JLCPCB) | 1
U2,U3 | AP2112K-1.8 | Package_TO_SOT_SMD:SOT-23-5 | C176944 | AP2112K-1.8TRG1 |  | LDO 1.8 V analog (AVDD, PVDD), 600 mA, low noise,LDO 1.8 V digital (DVDD, MVDD), 600 mA, low noise | 2
U5 | THS7314DR | Package_SO:SOIC-8_3.9x4.9mm_P1.27mm | C882751 | THS7314DR |  | 3-ch SDTV video amplifier, 6 dB, 8.5 MHz LPF, sync-tip clamp, SOIC-8 | 1
Y1 | 28.63636MHz | Crystal:Crystal_SMD_5032-2Pin_5.0x3.2mm | C112564 | X50322863636MSB2GI |  | YXC YSX530GA 5032, CL=20pF, ESR<=40R, +-20ppm | 1

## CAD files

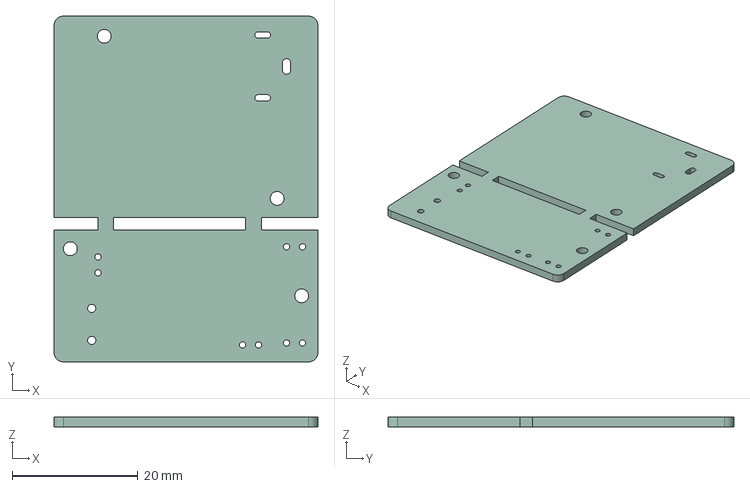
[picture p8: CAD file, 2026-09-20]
docs/mech/board.step
42.0 x 55.0 x 1.52 mm

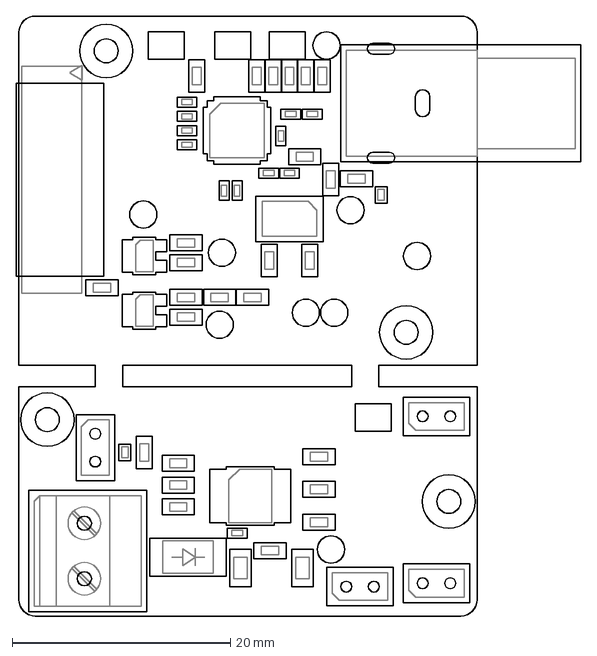
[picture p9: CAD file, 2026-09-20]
docs/mech/board-top-fab.dxf
51.8 x 55.0 mm

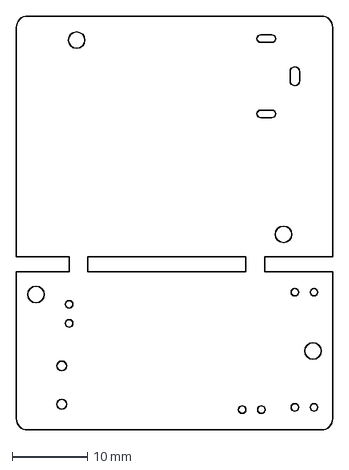
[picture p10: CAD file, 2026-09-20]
docs/mech/board-outline.dxf
42.0 x 55.0 mm

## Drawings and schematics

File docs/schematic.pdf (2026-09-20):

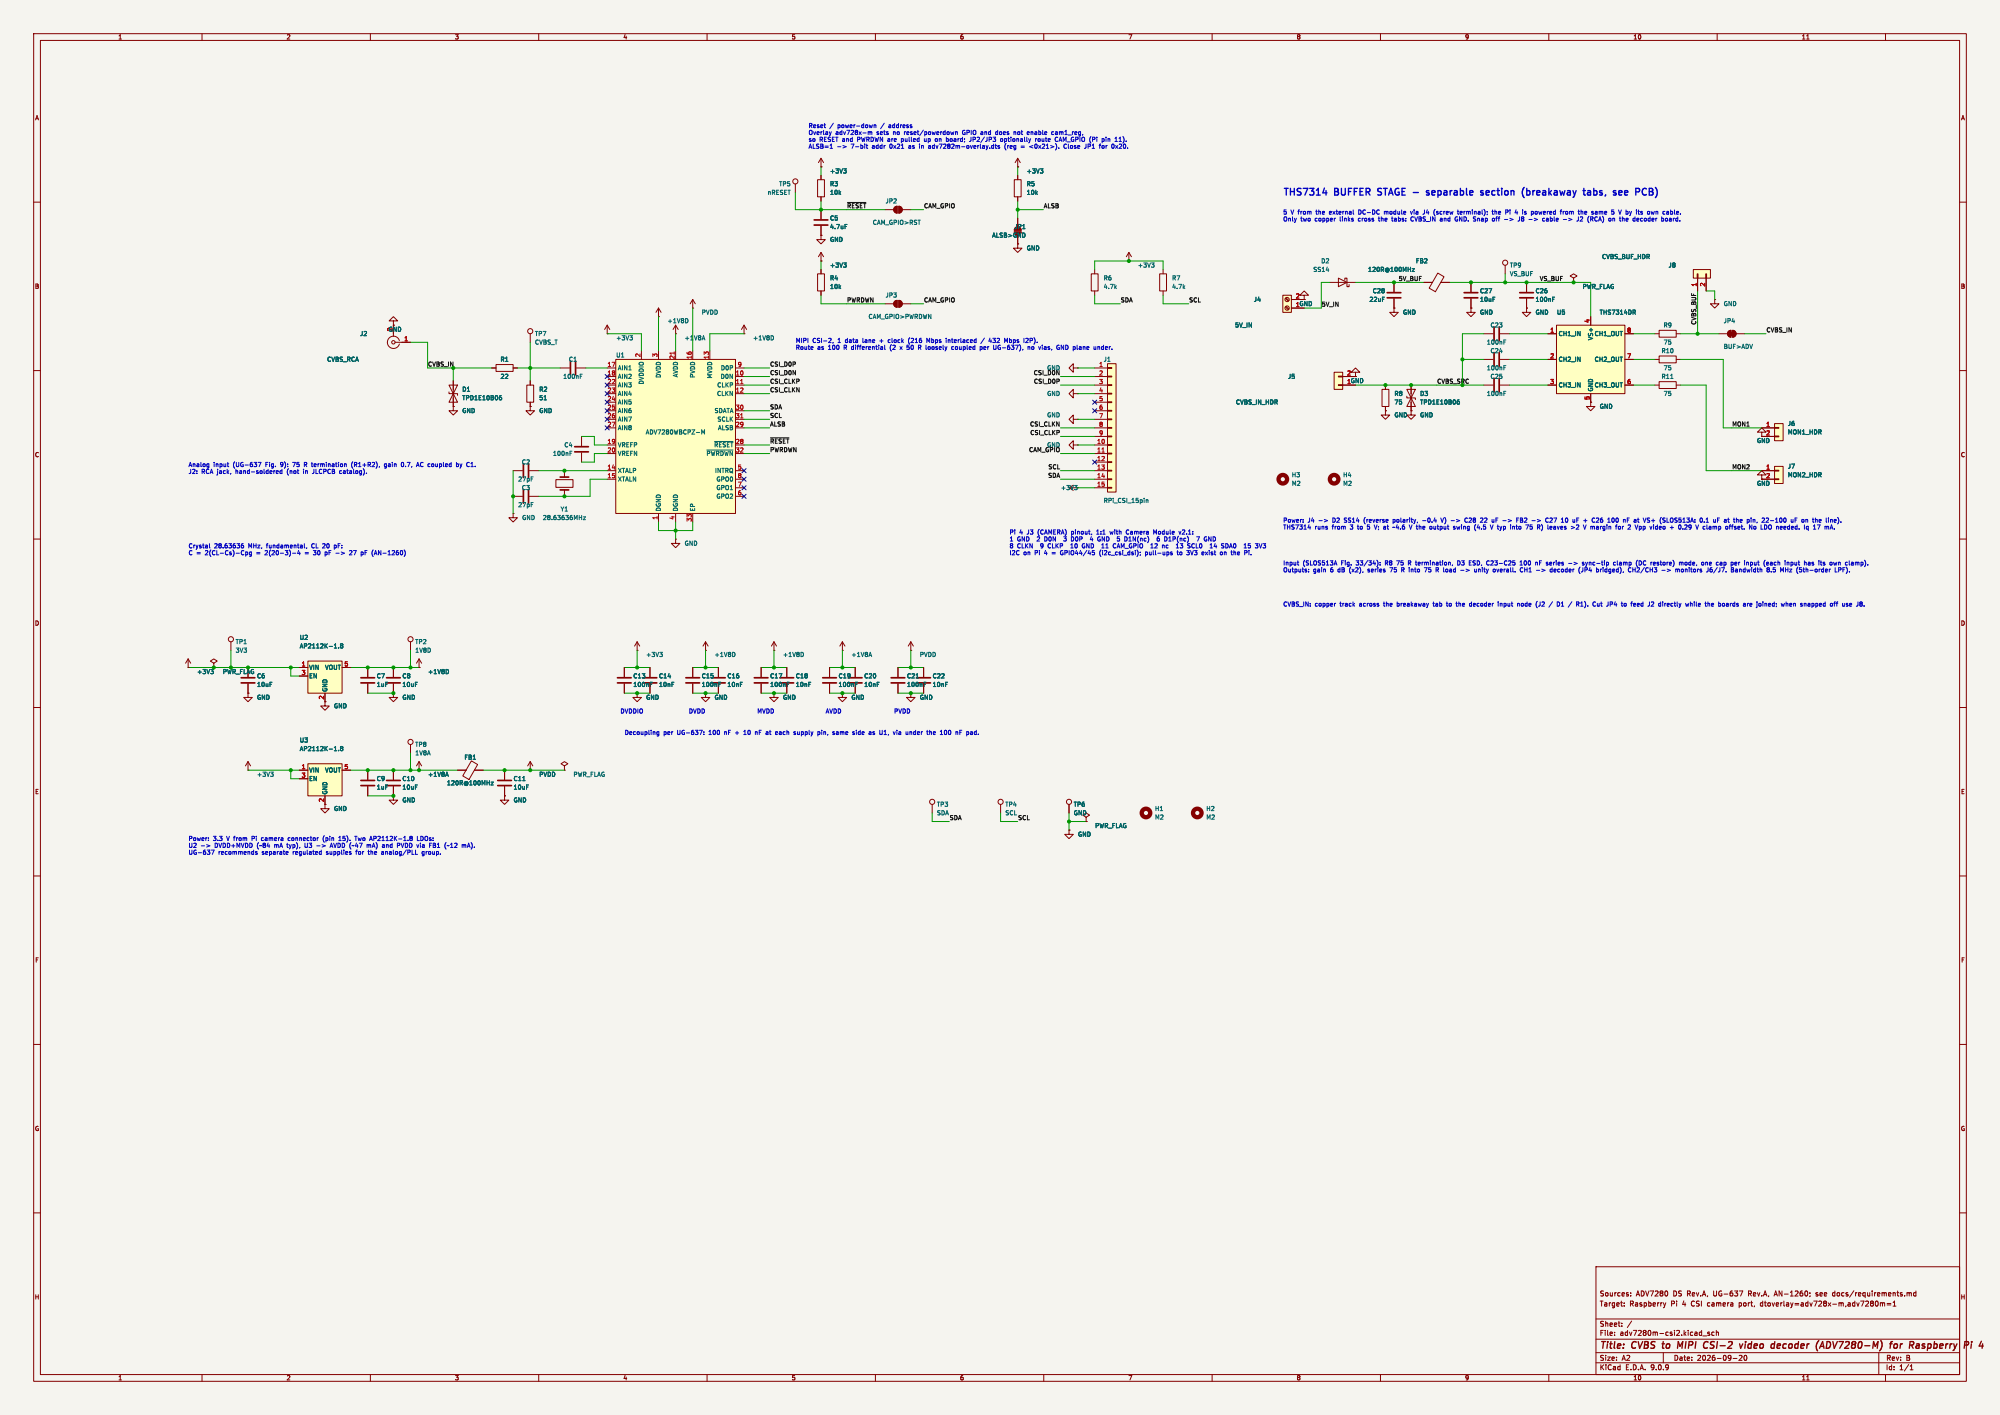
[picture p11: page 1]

THS7314 BUFFER STAGE - separable section (breakaway tabs, see PCB)

4 PVDD 16 EP 33 MVDD 13 D0P 9 D0N 10 CLKP 11 CLKN 12 SDATA 30 SCLK 31 ALSB 29 ~{RESET} 28 ~{PWRDWN} 32

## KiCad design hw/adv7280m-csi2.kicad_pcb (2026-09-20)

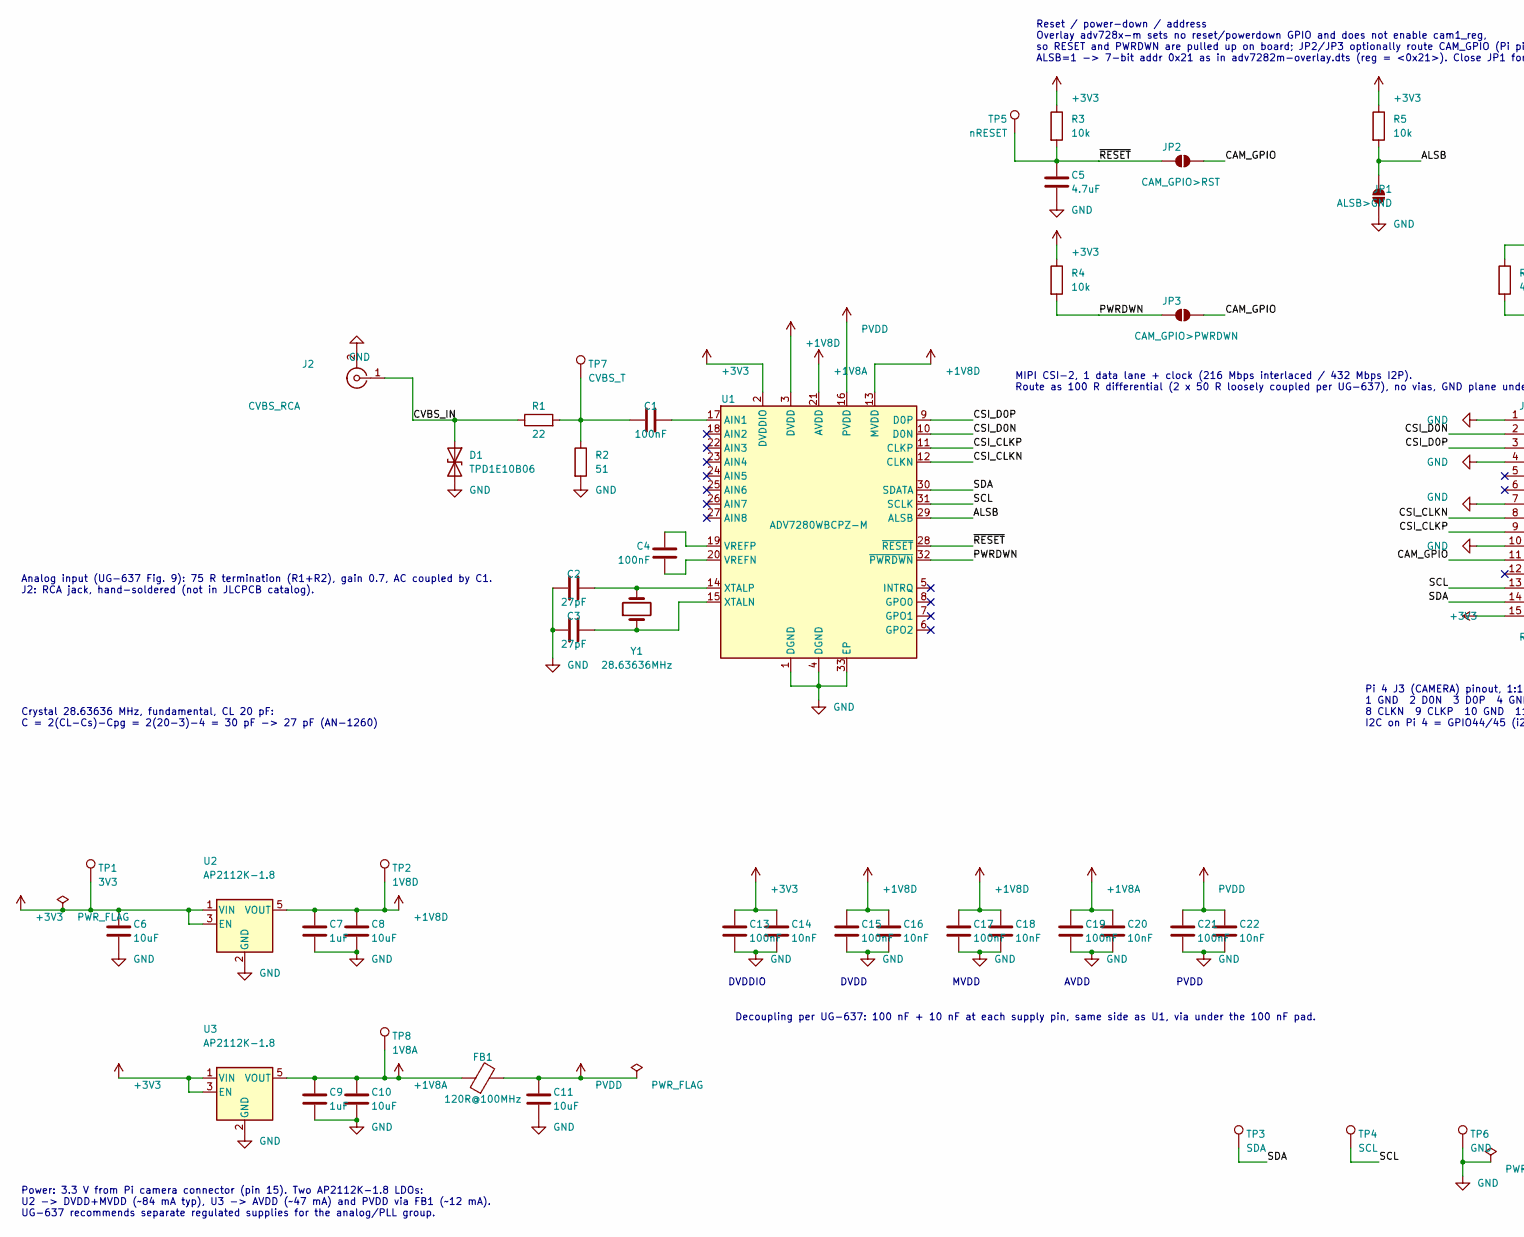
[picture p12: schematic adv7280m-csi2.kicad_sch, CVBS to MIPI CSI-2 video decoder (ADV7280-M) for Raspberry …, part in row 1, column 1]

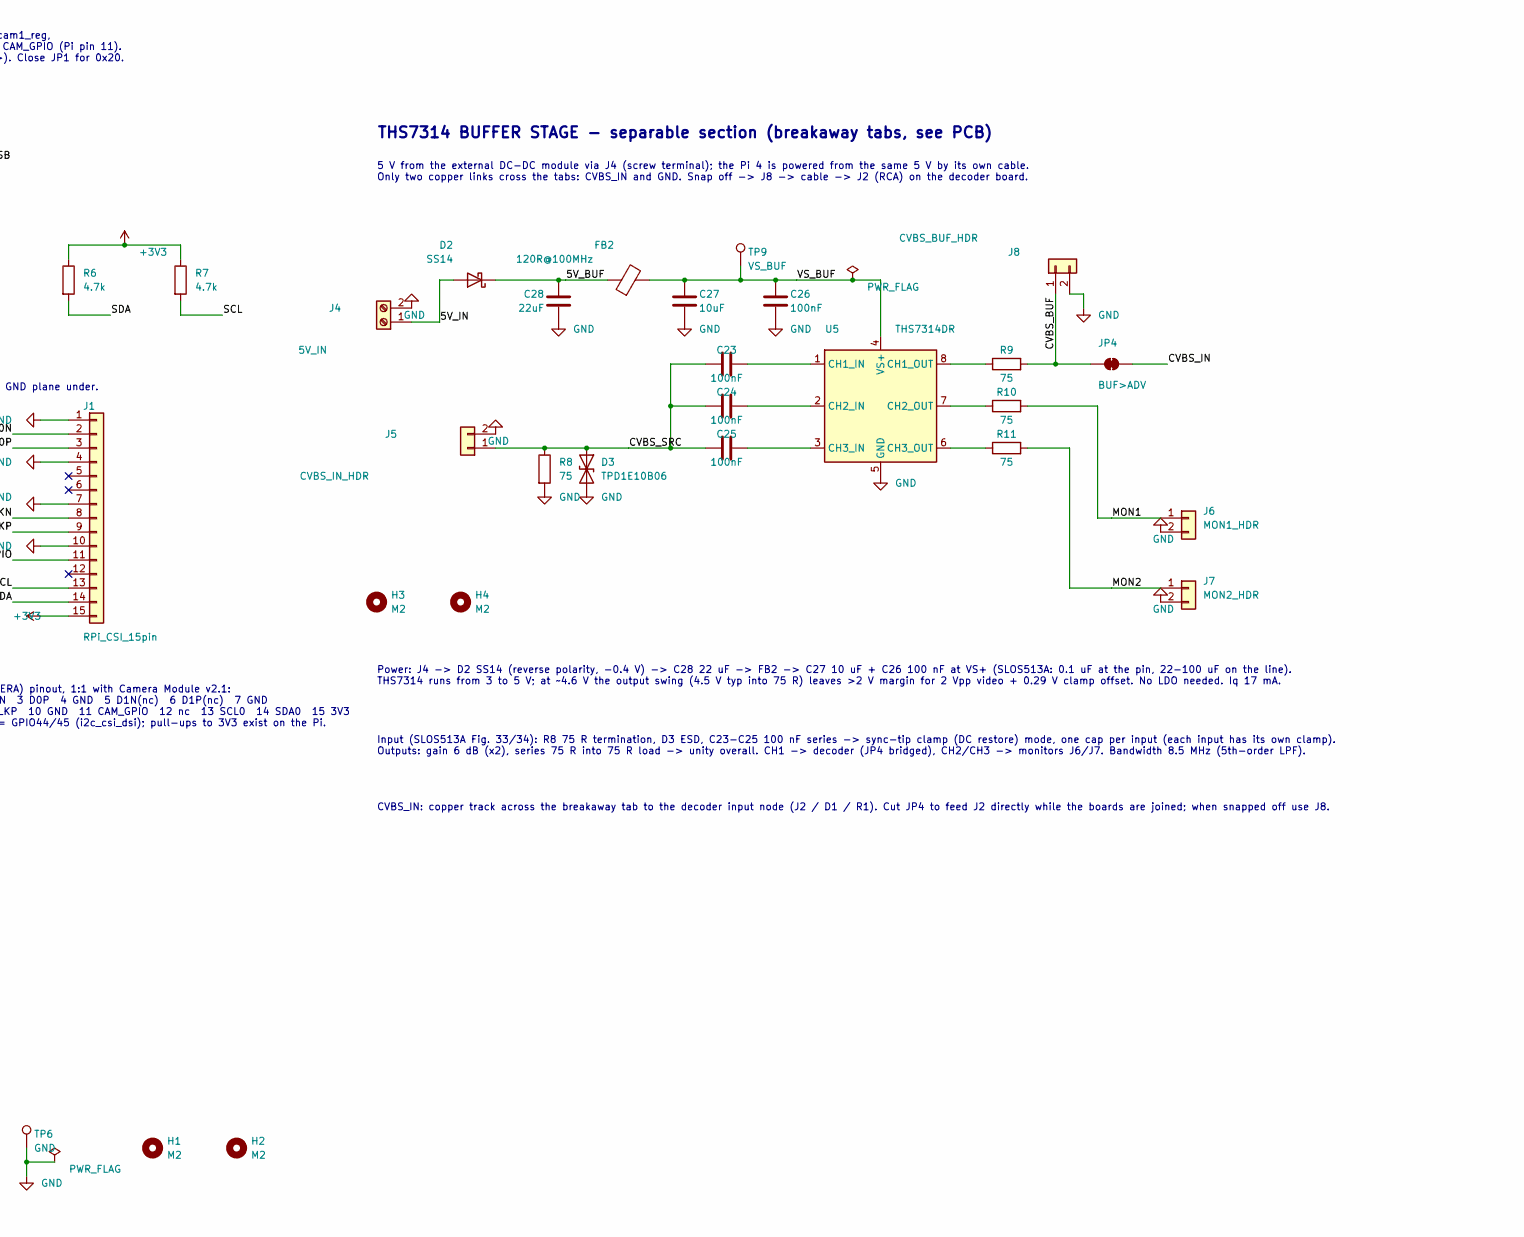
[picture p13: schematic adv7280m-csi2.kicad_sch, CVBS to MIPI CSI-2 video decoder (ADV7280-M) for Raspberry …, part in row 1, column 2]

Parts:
C1, C23, C24, C25: 100nF; C_0603_1608Metric; LCSC C14663
C2, C3: 27pF; C_0603_1608Metric; LCSC C92670
C4, C13, C15, C17, C19, C21, C26: 100nF; C_0402_1005Metric; LCSC C1525
C5: 4.7uF; C_0603_1608Metric; LCSC C19666
C6, C8, C10, C11: 10uF; C_0603_1608Metric; LCSC C19702
C7, C9: 1uF; C_0603_1608Metric; LCSC C15849
C14, C16, C18, C20, C22: 10nF; C_0402_1005Metric; LCSC C15195
C27: 10uF; C_0805_2012Metric; LCSC C15850
C28: 22uF; C_0805_2012Metric; LCSC C45783
D1, D3: TPD1E10B06; TI_X1SON-2_DPY0002A_1.0x0.6mm; LCSC C48260
D2: SS14; D_SMA; LCSC C2480
FB1, FB2: 120R@100MHz; L_0603_1608Metric; MPN BLM18PG121SN1D; LCSC C14709
H1, H2, H3, H4: M2; MountingHole_2.2mm_M2
J1: RPi_CSI_15pin; Amphenol_SFW15R-1STE1LF; MPN SFW15R-1STE1LF; LCSC C3168538
J2: CVBS_RCA; RCA_Multicomp_PSG01546_Horizontal; MPN PSG01546 or equivalent
J4: 5V_IN; TerminalBlock_Phoenix_MKDS-1,5-2-5.08_1x02_P5.08mm_Horizont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; MPN KF301-5.0-2P; LCSC C474881
J5: CVBS_IN_HDR; PinHeader_1x02_P2.54mm_Vertical; MPN PZ254V-11-02P; LCSC C492401
J6: MON1_HDR; PinHeader_1x02_P2.54mm_Vertical; MPN PZ254V-11-02P; LCSC C492401
J7: MON2_HDR; PinHeader_1x02_P2.54mm_Vertical; MPN PZ254V-11-02P; LCSC C492401
J8: CVBS_BUF_HDR; PinHeader_1x02_P2.54mm_Vertical; MPN PZ254V-11-02P; LCSC C492401
JP1: ALSB>GND; SolderJumper-2_P1.3mm_Open_RoundedPad1.0x1.5mm
JP2: CAM_GPIO>RST; SolderJumper-2_P1.3mm_Open_RoundedPad1.0x1.5mm
JP3: CAM_GPIO>PWRDWN; SolderJumper-2_P1.3mm_Open_RoundedPad1.0x1.5mm
JP4: BUF>ADV; SolderJumper-2_P1.3mm_Bridged_RoundedPad1.0x1.5mm
R1: 22; R_0603_1608Metric; LCSC C23345
R2: 51; R_0603_1608Metric; LCSC C23197
R3, R4, R5: 10k; R_0603_1608Metric; LCSC C25804
R6, R7: 4.7k; R_0603_1608Metric; LCSC C23162
R8, R9, R10, R11: 75; R_0603_1608Metric; LCSC C4275
TP1: 3V3; TestPoint_Pad_D1.5mm
TP2: 1V8D; TestPoint_Pad_D1.5mm
TP3: SDA; TestPoint_Pad_D1.5mm
TP4: SCL; TestPoint_Pad_D1.5mm
TP5: nRESET; TestPoint_Pad_D1.5mm
TP6: GND; TestPoint_Pad_D1.5mm
TP7: CVBS_T; TestPoint_Pad_D1.5mm
TP8: 1V8A; TestPoint_Pad_D1.5mm
TP9: VS_BUF; TestPoint_Pad_D1.5mm
U1: ADV7280WBCPZ-M; QFN-32-1EP_5x5mm_P0.5mm_EP3.6x3.6mm; MPN ADV7280WBCPZ-M; LCSC C662261
U2, U3: AP2112K-1.8; SOT-23-5; MPN AP2112K-1.8TRG1; LCSC C176944
U5: THS7314DR; SOIC-8_3.9x4.9mm_P1.27mm; MPN THS7314DR; LCSC C882751
Y1: 28.63636MHz; Crystal_SMD_5032-2Pin_5.0x3.2mm; MPN X50322863636MSB2GI; LCSC C112564

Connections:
+1V8A: C9.1, C10.1, C19.1, C20.1, FB1.1, TP8.1, U1.21 (AVDD), U3.5 (VOUT)
+1V8D: C7.1, C8.1, C15.1, C16.1, C17.1, C18.1, TP2.1, U1.3 (DVDD), U1.13 (MVDD), U2.5 (VOUT)
+3V3: C6.1, C13.1, C14.1, J1.15, R3.1, R4.1, R5.1, R6.1, R7.1, TP1.1, U1.2 (DVDDIO), U2.1 (VIN), U2.3 (EN), U3.1 (VIN), U3.3 (EN)
/5V_BUF: C28.1, D2.1 (K), FB2.1
/5V_IN: D2.2 (A), J4.1
/ALSB: JP1.2 (B), R5.2, U1.29 (ALSB)
/CAM_GPIO: J1.11, JP2.2 (B), JP3.2 (B)
/CSI_CLKN: J1.8, U1.12 (CLKN)
/CSI_CLKP: J1.9, U1.11 (CLKP)
/CSI_D0N: J1.2, U1.10 (D0N)
/CSI_D0P: J1.3, U1.9 (D0P)
/CVBS_BUF: J8.1, JP4.1 (A), R9.2
/CVBS_IN: D1.1 (A1), J2.1 (In), JP4.2 (B), R1.1
/CVBS_SRC: C23.1, C24.1, C25.1, D3.1 (A1), J5.1, R8.1
/MON1: J6.1, R10.2
/MON2: J7.1, R11.2
/PWRDWN: JP3.1 (A), R4.2, U1.32 (~PWRDWN)
/SCL: J1.13, R7.2, TP4.1, U1.31 (SCLK)
/SDA: J1.14, R6.2, TP3.1, U1.30 (SDATA)
/VS_BUF: C26.1, C27.1, FB2.2, TP9.1, U5.4 (VS+)
/~RESET: C5.1, JP2.1 (A), R3.2, TP5.1, U1.28 (~RESET)
GND: C2.1, C3.1, C5.2, C6.2, C7.2, C8.2, C9.2, C10.2, C11.2, C13.2, C14.2, C15.2, C16.2, C17.2, C18.2, C19.2, C20.2, C21.2, C22.2, C26.2, C27.2, C28.2, D1.2 (A2), D3.2 (A2), J1.1, J1.4, J1.7, J1.10, J2.2 (Ext), J4.2, J5.2, J6.2, J7.2, J8.2, JP1.1 (A), R2.2, R8.2, TP6.1, U1.1 (DGND), U1.4 (DGND), U1.33 (EP), U2.2 (GND), U3.2 (GND), U5.5 (GND)
unnamed: C1.1, R1.2, R2.1, TP7.1
unnamed: C1.2, U1.17 (AIN1)
unnamed: C4.2, U1.20 (VREFN)
unnamed: C4.1, U1.19 (VREFP)
unnamed: C3.2, U1.15 (XTALN), Y1.1
unnamed: C2.2, U1.14 (XTALP), Y1.2
unnamed: C23.2, U5.1 (CH1_IN)
unnamed: R9.1, U5.8 (CH1_OUT)
unnamed: C24.2, U5.2 (CH2_IN)
unnamed: R10.1, U5.7 (CH2_OUT)
unnamed: C25.2, U5.3 (CH3_IN)
unnamed: R11.1, U5.6 (CH3_OUT)
PVDD: C11.1, C21.1, C22.1, FB1.2, U1.16 (PVDD)

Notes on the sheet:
Pi 4 J3 (CAMERA) pinout, 1:1 with Camera Module v2.1: 1 GND 2 D0N 3 D0P 4 GND 5 D1N(nc) 6 D1P(nc) 7 GND 8 CLKN 9 CLKP 10 GND 11 CAM_GPIO 12 nc 13 SCL0 14 SDA0 15 3V3 I2C on Pi 4 = GPIO44/45 (i2c_csi_dsi); pull-ups to 3V3 exist on the Pi.
Reset / power-down / address Overlay adv728x-m sets no reset/powerdown GPIO and does not enable cam1_reg, so RESET and PWRDWN are pulled up on board; JP2/JP3 optionally route CAM_GPIO (Pi pin 11). ALSB=1 -> 7-bit addr 0x21 as in adv7282m-overlay.dts (reg = <0x21>). Close JP1 for 0x20.
Power: 3.3 V from Pi camera connector (pin 15). Two AP2112K-1.8 LDOs: U2 -> DVDD+MVDD (~84 mA typ), U3 -> AVDD (~47 mA) and PVDD via FB1 (~12 mA). UG-637 recommends separate regulated supplies for the analog/PLL group.
DVDDIO
DVDD
MVDD
AVDD
PVDD
Decoupling per UG-637: 100 nF + 10 nF at each supply pin, same side as U1, via under the 100 nF pad.
Analog input (UG-637 Fig. 9): 75 R termination (R1+R2), gain 0.7, AC coupled by C1. J2: RCA jack, hand-soldered (not in JLCPCB catalog).
Crystal 28.63636 MHz, fundamental, CL 20 pF: C = 2(CL-Cs)-Cpg = 2(20-3)-4 = 30 pF -> 27 pF (AN-1260)
MIPI CSI-2, 1 data lane + clock (216 Mbps interlaced / 432 Mbps I2P). Route as 100 R differential (2 x 50 R loosely coupled per UG-637), no vias, GND plane under.
THS7314 BUFFER STAGE - separable section (breakaway tabs, see PCB)
5 V from the external DC-DC module via J4 (screw terminal); the Pi 4 is powered from the same 5 V by its own cable. Only two copper links cross the tabs: CVBS_IN and GND. Snap off -> J8 -> cable -> J2 (RCA) on the decoder board.
Power: J4 -> D2 SS14 (reverse polarity, -0.4 V) -> C28 22 uF -> FB2 -> C27 10 uF + C26 100 nF at VS+ (SLOS513A: 0.1 uF at the pin, 22-100 uF on the line). THS7314 runs from 3 to 5 V; at ~4.6 V the output swing (4.5 V typ into 75 R) leaves >2 V margin for 2 Vpp video + 0.29 V clamp offset. No LDO ne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
Input (SLOS513A Fig. 33/34): R8 75 R termination, D3 ESD, C23-C25 100 nF series -> sync-tip clamp (DC restore) mode, one cap per input (each input has its own clamp). Outputs: gain 6 dB (x2), series 75 R into 75 R load -> unity overall. CH1 -> decoder (JP4 bridged), CH2/CH3 -> monitors J6/J7. Bandw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
CVBS_IN: copper track across the breakaway tab to the decoder input node (J2 / D1 / R1). Cut JP4 to feed J2 directly while the boards are joined; when snapped off use J8.

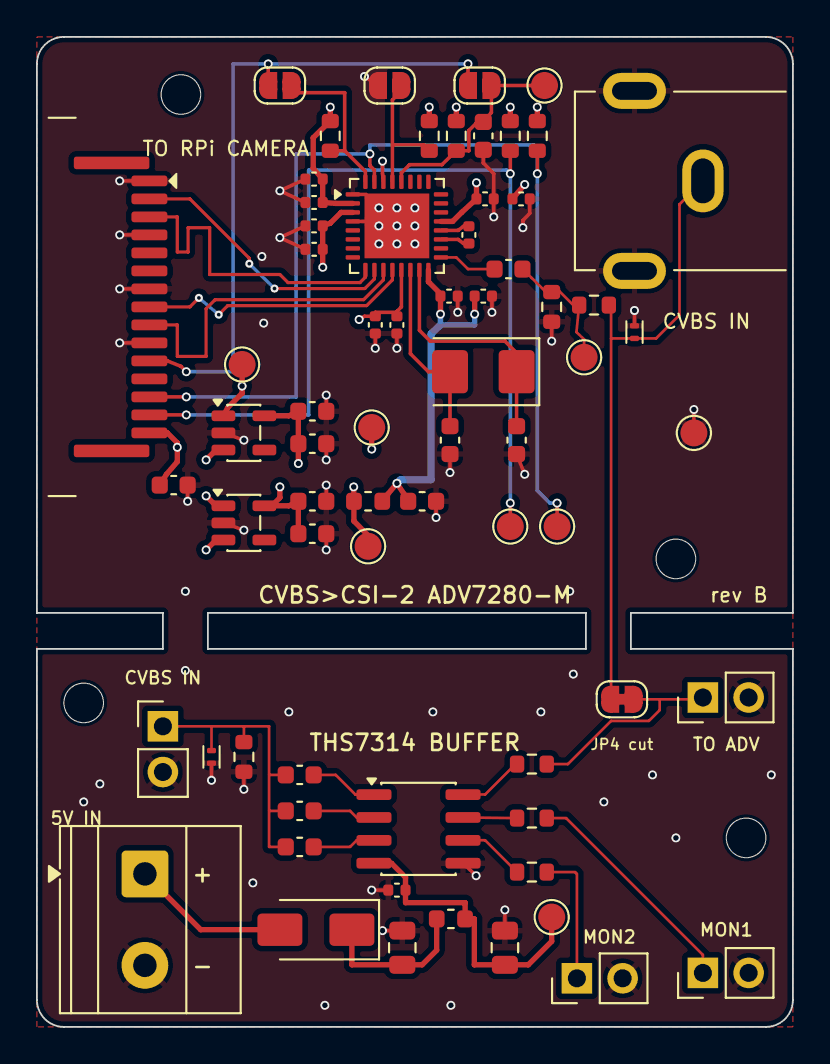
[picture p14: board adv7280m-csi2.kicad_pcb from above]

Board: 4 copper layers, 42.0 x 55.0 mm, 72 parts (0 on the bottom side), 35 nets.

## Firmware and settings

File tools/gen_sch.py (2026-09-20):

"""Generate the KiCad 9 schematic hw/adv7280m-csi2.kicad_sch (single sheet, A3)."""
import os, sys, math, uuid
sys.path.insert(0, os.path.dirname(__file__))
from kisexp import *

HW = os.path.join(os.path.dirname(__file__), '..', 'hw')
KSYM = '/usr/share/kicad/symbols'
PROJECT = 'adv7280m-csi2'
ROOT_UUID = '3f6a0c2e-7c1b-4a52-9d3e-adv7280m0001'.replace('adv7280m', 'a0b1c2d3')  # fixed uuid for reproducibility

LIBS = {'Device': 'Device.kicad_sym', 'Regulator_Linear': 'Regulator_Linear.kicad_sym', 'power': 'power.kicad_sym',
        'Connector_Generic': 'Connector_Generic.kicad_sym', 'Connector': 'Connector.kicad_sym', 'Jumper': 'Jumper.kicad_sym',
        'Mechanical': 'Mechanical.kicad_sym', 'adv-parts': os.path.join(HW, 'lib', 'adv-parts.kicad_sym')}

def g(v):  # snap to 1.27 grid
    return round(round(v / 1.27) * 1.27, 4)

def eff(size=1.27, hide=False, justify=None):
    e = S('effects', S('font', S('size', size, size)))
    if justify: e.append(S('justify', *[Sym(j) for j in justify.split()]))
    if hide: e.append(S('hide', Sym('yes')))
    return e

class Part:
    def __init__(self, sch, libid, ref, value, x, y, rot, fp, lcsc, desc, extra, dnp, in_bom, on_board, hide_ref=False, hide_val=False, ref_pos=None, val_pos=None, prop_angle=None):
        self.sch, self.libid, self.ref, self.value = sch, libid, ref, value
        self.x, self.y, self.rot = x, y, rot
        self.fp, self.lcsc, self.desc, self.extra = fp, lcsc, desc, extra or {}
        self.dnp, self.in_bom, self.on_board = dnp, in_bom, on_board
        self.hide_ref, self.hide_val = hide_ref, hide_val
        self.ref_pos, self.val_pos = ref_pos, val_pos
        self.prop_angle = prop_angle
        self.uuid = str(uuid.uuid5(uuid.NAMESPACE_URL, 'adv7280m-csi2/sym/' + ref))
        self.sym = sch.libsym(libid)
        self.pins = {p['number']: p for p in symbol_pins(self.sym)}
    def pin(self, num):
        p = self.pins[str(num)]
        r = math.radians(self.rot)
        c, s = round(math.cos(r)), round(math.sin(r))
        xp = p['x'] * c - p['y'] * s
        yp = p['x'] * s + p['y'] * c
        return (round(self.x + xp, 4), round(self.y - yp, 4))
    def pin_points(self):
        return [self.pin(n) for n in self.pins]

class Sch:
    def __init__(self):
        self.libsyms = {}
        self.parts = []
        self.wires = []
        self.labels = []
        self.ncs = []
        self.texts = []
        self.pwr_n = 0
    def libsym(self, libid):
        if libid not in self.libsyms:
            lib, name = libid.split(':')
            path = LIBS[lib] if lib == 'adv-parts' else os.path.join(KSYM, LIBS[lib])
            s = flatten_symbol(load_lib(path), name)
            s[1] = libid
            self.libsyms[libid] = s
        return self.libsyms[libid]
    def place(self, libid, ref, value, x, y, rot=0, fp='', lcsc='', desc='', extra=None, dnp=False, in_bom=True, on_board=True, **kw):
        p = Part(self, libid, ref, value, g(x), g(y), rot, fp, lcsc, desc, extra, dnp, in_bom, on_board, **kw)
        self.parts.append(p)
        return p
    def power(self, value, x, y, rot=0, lib='power', **kw):
        self.pwr_n += 1
        p = Part(self, f'{lib}:{value}', f'#PWR{self.pwr_n:03d}', value, g(x), g(y), rot, '', '', '', {}, False, False, True, hide_ref=True, **kw)
        self.parts.append(p)
        return p
    def flag(self, x, y, rot=0):
        self.pwr_n += 1
        p = Part(self, 'power:PWR_FLAG', f'#FLG{self.pwr_n:03d}', 'PWR_FLAG', g(x), g(y), rot, '', '', '', {}, False, False, True, hide_ref=True)
        self.parts.append(p)
        return p
    def wire(self, a, b):
        a = (g(a[0]), g(a[1])); b = (g(b[0]), g(b[1]))
        if a == b: return
        assert a[0] == b[0] or a[1] == b[1], f'non-orthogonal wire {a}-{b}'
        self.wires.append((a, b))
    def path(self, *pts):
        for a, b in zip(pts, pts[1:]): self.wire(a, b)
    def label(self, name, x, y, rot=0):
        self.labels.append((name, g(x), g(y), rot))
    def nc(self, pt):
        self.ncs.append((g(pt[0]), g(pt[1])))
    def text(self, s, x, y, size=1.27, bold=False):
        self.texts.append((s, g(x), g(y), size, bold))

    # ---------- wire splitting + junction computation ----------
    def _split_wires(self):
        """Split wire segments at every point where another wire ends or a pin/label sits in the interior
        (KiCad connectivity only joins wires at segment endpoints)."""
        pts = set()
        for a, b in self.wires: pts.add(a); pts.add(b)
        for p in self.parts:
            for pt in p.pin_points(): pts.add(pt)
        for name, x, y, rot in self.labels: pts.add((x, y))
        out = []
        for a, b in self.wires:
            inner = []
            for pt in pts:
                if a[0] == b[0] == pt[0] and min(a[1], b[1]) < pt[1] < max(a[1], b[1]): inner.append(pt)
                elif a[1] == b[1] == pt[1] and min(a[0], b[0]) < pt[0] < max(a[0], b[0]): inner.append(pt)
            chain = [a] + sorted(inner, key=lambda q: (abs(q[0] - a[0]) + abs(q[1] - a[1]))) + [b]
            for u, v in zip(chain, chain[1:]): out.append((u, v))
        self.wires = out

    def junctions(self):
        from collections import defaultdict
        self._split_wires()
        ends = defaultdict(int)
        for a, b in self.wires:
            ends[a] += 1; ends[b] += 1
        pinpts = defaultdict(int)
        for p in self.parts:
            for pt in p.pin_points(): pinpts[pt] += 1
        js = []
        for pt in set(list(ends) + list(pinpts)):
            if ends[pt] + pinpts[pt] >= 3: js.append(pt)
        return js

    # ---------- emit ----------
    def emit(self, title, rev, date):
        root = S('kicad_sch', S('version', 20250114), S('generator', 'eeschema'), S('generator_version', '9.0'),
                 S('uuid', ROOT_UUID), S('paper', 'A2'),
                 S('title_block', S('title', title), S('date', date), S('rev', rev),
                   S('comment', 1, 'Target: Raspberry Pi 4 CSI camera port, dtoverlay=adv728x-m,adv7280m=1'),
                   S('comment', 2, 'Sources: ADV7280 DS Rev.A, UG-637 Rev.A, AN-1260; see docs/requirements.md')))
        ls = S('lib_symbols')
        for k in sorted(self.libsyms): ls.append(self.libsyms[k])
        root.append(ls)
        for pt in self.junctions():
            root.append(S('junction', S('at', pt[0], pt[1]), S('diameter', 0), S('color', 0, 0, 0, 0), S('uuid', new_uuid())))
        for pt in self.ncs:
            root.append(S('no_connect', S('at', pt[0], pt[1]), S('uuid', new_uuid())))
        for a, b in self.wires:
            root.append(S('wire', S('pts', S('xy', a[0], a[1]), S('xy', b[0], b[1])),
                          S('stroke', S('width', 0), S('type', Sym('default'))), S('uuid', new_uuid())))
        for name, x, y, rot in self.labels:
            just = 'right bottom' if rot == 180 else 'left bottom'
            root.append(S('label', name, S('at', x, y, rot), S('effects', S('font', S('size', 1.27, 1.27)), S('justify', *[Sym(j) for j in just.split()])), S('uuid', new_uuid())))
        for s, x, y, size, bold in self.texts:
            f = S('font', S('size', size, size))
            if bold: f.append(S('bold', Sym('yes')))
            root.append(S('text', s, S('exclude_from_sim', Sym('no')), S('at', x, y, 0), S('effects', f, S('justify', Sym('left'), Sym('bottom'))), S('uuid', new_uuid())))
        for p in self.parts:
            root.append(self.emit_part(p))
        root.append(S('sheet_instances', S('path', '/', S('page', '1'))))
        return root

    def emit_part(self, p):
        yn = lambda b: Sym('yes' if b else 'no')
        node = S('symbol', S('lib_id', p.libid), S('at', p.x, p.y, p.rot), S('unit', 1),
                 S('exclude_from_sim', Sym('no')), S('in_bom', yn(p.in_bom)), S('on_board', yn(p.on_board)), S('dnp', yn(p.dnp)),
                 S('uuid', p.uuid))
        # property placement
        if p.ref_pos: rx, ry, rj = p.ref_pos
        elif p.rot in (0, 180): rx, ry, rj = p.x + 2.54, p.y - 1.27, 'left'
        else: rx, ry, rj = p.x, p.y - 2.54, None
        if p.val_pos: vx, vy, vj = p.val_pos
        elif p.rot in (0, 180): vx, vy, vj = p.x + 2.54, p.y + 1.27, 'left'
        else: vx, vy, vj = p.x, p.y + 2.54, None
        pa = p.prop_angle if p.prop_angle is not None else (90 if p.rot in (90, 270) else 0)
        node.append(S('property', 'Reference', p.ref, S('at', g(rx), g(ry), pa), eff(hide=p.hide_ref, justify=rj)))
        node.append(S('property', 'Value', p.value, S('at', g(vx), g(vy), pa), eff(hide=p.hide_val, justify=vj)))
        node.append(S('property', 'Footprint', p.fp, S('at', p.x, p.y, 0), eff(hide=True)))
        ds = ''
        for pr in find_all(p.sym, 'property'):
            if pr[1] == 'Datasheet': ds = pr[2]
        node.append(S('property', 'Datasheet', p.extra.get('Datasheet', ds), S('at', p.x, p.y, 0), eff(hide=True)))
        node.append(S('property', 'Description', p.desc, S('at', p.x, p.y, 0), eff(hide=True)))
        if not p.ref.startswith('#'):
            node.append(S('property', 'LCSC', p.lcsc, S('at', p.x, p.y, 0), eff(hide=True)))
            for k, v in p.extra.items():
                if k == 'Datasheet': continue
                node.append(S('property', k, v, S('at', p.x, p.y, 0), eff(hide=True)))
        for num in p.pins:
            node.append(S('pin', num, S('uuid', new_uuid())))
        node.append(S('instances', S('project', PROJECT, S('path', '/' + ROOT_UUID, S('reference', p.ref), S('unit', 1)))))
        return node

# ------------------------------------------------------------------------------------------------
FP = dict(R='Resistor_SMD:R_0603_1608Metric', C0402='Capacitor_SMD:C_0402_1005Metric', C0603='Capacitor_SMD:C_0603_1608Metric',
          L='Inductor_SMD:L_0603_1608Metric', SOT235='Package_TO_SOT_SMD:SOT-23-5', XTAL='Crystal:Crystal_SMD_5032-2Pin_5.0x3.2mm',
          JP='Jumper:SolderJumper-2_P1.3mm_Open_RoundedPad1.0x1.5mm', TP='TestPoint:TestPoint_Pad_D1.5mm',
          HOLE='MountingHole:MountingHole_2.2mm_M2', ESD='adv-parts:TI_X1SON-2_DPY0002A_1.0x0.6mm',
          FFC='adv-parts:Amphenol_SFW15R-1STE1LF', RCA='adv-parts:RCA_Multicomp_PSG01546_Horizontal',
          QFN='Package_DFN_QFN:QFN-32-1EP_5x5mm_P0.5mm_EP3.6x3.6mm',
          C0805='Capacitor_SMD:C_0805_2012Metric', SMA='Diode_SMD:D_SMA', SOIC8='Package_SO:SOIC-8_3.9x4.9mm_P1.27mm',
          JPB='Jumper:SolderJumper-2_P1.3mm_Bridged_RoundedPad1.0x1.5mm', TERM='TerminalBlock_Phoenix:TerminalBlock_Phoenix_MKDS-1,5-2-5.08_1x02_P5.08mm_Horizontal',
          HDR2='Connector_PinHeader_2.54mm:PinHeader_1x02_P2.54mm_Vertical')

LCSC = {'R22': 'C23345', 'R51': 'C23197', 'R10k': 'C25804', 'R4k7': 'C23162',
        'C100n_0402': 'C1525', 'C10n_0402': 'C15195', 'C100n_0603': 'C14663', 'C1u': 'C15849', 'C4u7': 'C19666', 'C10u': 'C19702', 'C27p': 'C92670',
        'XTAL': 'C112564', 'ESD': 'C48260', 'FB': 'C14709', 'LDO': 'C176944', 'FFC': 'C3168538', 'U1': 'C662261',
        'R75': 'C4275', 'C10u_0805': 'C15850', 'C22u_0805': 'C45783', 'SS14': 'C2480', 'THS': 'C882751', 'TERM': 'C474881', 'HDR2': 'C492401'}

def build():
    s = Sch()
    # ---------------- U1 ----------------
    Ux, Uy = 200.66, 129.54
    U1 = s.place('adv-parts:ADV7280WBCPZ-M', 'U1', 'ADV7280WBCPZ-M', Ux, Uy, 0, FP['QFN'], LCSC['U1'],
                 'SDTV video decoder, MIPI CSI-2 output, LFCSP-32 (hand-soldered by owner, not by JLCPCB)',
                 extra={'Assemble': 'no', 'Manufacturer': 'Analog Devices', 'MPN': 'ADV7280WBCPZ-M'},
                 ref_pos=(Ux - 17.78, Uy - 24.13, 'left'), val_pos=(Ux, Uy - 1.27, None))
    def UP(name):
        for n, p in U1.pins.items():
            if p['name'] == name: return U1.pin(n)
        raise KeyError(name)

    # ---------------- analog input ----------------
    ain1 = UP('AIN1')                                   # (180.34, 109.22)
    yA = ain1[1]
    C1 = s.place('Device:C', 'C1', '100nF', 170.18, yA, 90, FP['C0603'], LCSC['C100n_0603'], 'AC coupling, 50 V X7R 0603')
    s.wire(ain1, C1.pin(2))
    xT = 157.48                                          # termination node
    s.wire(C1.pin(1), (xT, yA))
    R1 = s.place('Device:R', 'R1', '22', 149.86, yA, 90, FP['R'], LCSC['R22'], 'Series termination (24 R in UG-637 Fig. 9; 22 R = nearest JLCPCB Basic)')
    s.wire(R1.pin(2), (xT, yA))
    R2 = s.place('Device:R', 'R2', '51', xT, 116.84, 0, FP['R'], LCSC['R51'], 'Shunt termination, 22+51 = 73 R')
    s.wire((xT, yA), R2.pin(1))
    s.power('GND', *R2.pin(2))
    TP7 = s.place('Connector:TestPoint', 'TP7', 'CVBS_T', xT, 101.6, 0, FP['TP'], '', 'CVBS after termination', ref_pos=(xT + 1.27, 99.06, 'left'), val_pos=(xT + 1.27, 101.6, 'left'))
    s.wire(TP7.pin(1), (xT, yA))
    xE = 134.62
    s.wire(R1.pin(1), (xE, yA))
    D1 = s.place('Device:D_TVS', 'D1', 'TPD1E10B06', xE, 116.84, 270, FP['ESD'], LCSC['ESD'], 'ESD TVS, 12 pF, bidirectional', ref_pos=(xE + 2.54, 115.57, 'left'), val_pos=(xE + 2.54, 118.11, 'left'))
    s.wire((xE, yA), D1.pin(1))
    s.power('GND', *D1.pin(2))
    xJ = 127.0
    s.wire((xE, yA), (xJ, yA))
    J2 = s.place('Connector:Conn_Coaxial', 'J2', 'CVBS_RCA', 116.84, 101.6, 180, FP['RCA'], '', 'RCA jack, hand-soldered (not stocked by JLCPCB)',
                 extra={'Assemble': 'no', 'MPN': 'PSG01546 or equivalent'}, ref_pos=(109.22, 99.06, 'left'), val_pos=(106.68, 106.68, 'left'))
    s.path(J2.pin(1), (xJ, J2.pin(1)[1]), (xJ, yA))
    s.power('GND', J2.pin(2)[0], J2.pin(2)[1], 180)
    s.label('CVBS_IN', xJ, yA - 0.0, 0)
    for nm in ['AIN2', 'AIN3', 'AIN4', 'AIN5', 'AIN6', 'AIN7', 'AIN8']:
        s.nc(UP(nm))
    # VREF
    vp, vn = UP('VREFP'), UP('VREFN')
    C4 = s.place('Device:C', 'C4', '100nF', 172.72, 133.35, 0, FP['C0402'], LCSC['C100n_0402'], 'VREFP-VREFN, close to U1', ref_pos=(170.18, 132.08, 'right'), val_pos=(170.18, 134.62, 'right'))
    s.path(vp, (176.53, vp[1]), (176.53, C4.pin(1)[1]), C4.pin(1))
    s.path(vn, (176.53, vn[1]), (176.53, C4.pin(2)[1]), C4.pin(2))
    # crystal
    xp, xn = UP('XTALP'), UP('XTALN')
    Y1 = s.place('Device:Crystal', 'Y1', '28.63636MHz', 167.64, 143.51, 90, FP['XTAL'], LCSC['XTAL'], 'YXC YSX530GA 5032, CL=20pF, ESR<=40R, +-20ppm',
                 extra={'MPN': 'X50322863636MSB2GI'}, ref_pos=(167.64, 151.13, None), val_pos=(167.64, 153.67, None))
    s.wire(xp, Y1.pin(2))                                              # XTALP straight to crystal top pin (y=139.7)
    s.path(xn, (175.26, xn[1]), (175.26, Y1.pin(1)[1]), Y1.pin(1))
    C2 = s.place('Device:C', 'C2', '27pF', 156.21, Y1.pin(2)[1], 90, FP['C0603'], LCSC['C27p'], 'Crystal load, C0G')
    C3 = s.place('Device:C', 'C3', '27pF', 156.21, Y1.pin(1)[1], 90, FP['C0603'], LCSC['C27p'], 'Crystal load, C0G')
    s.wire(Y1.pin(2), C2.pin(2)); s.wire(Y1.pin(1), C3.pin(2))
    s.wire(C2.pin(1), C3.pin(1))
    s.wire(C3.pin(1), (C3.pin(1)[0], 152.4))
    s.power('GND', C3.pin(1)[0], 152.4)

    # ---------------- supplies at U1 ----------------
    dvddio, dvdd, avdd, pvdd, mvdd = UP('DVDDIO'), UP('DVDD'), UP('AVDD'), UP('PVDD'), UP('MVDD')
    s.path(dvddio, (dvddio[0], 99.06), (180.34, 99.06)); s.power('+3V3', 180.34, 99.06)
    s.path(dvdd, (dvdd[0], 93.98)); s.power('+1V8D', dvdd[0], 93.98, lib='adv-parts')
    s.path(avdd, (avdd[0], 99.06)); s.power('+1V8A', avdd[0], 99.06, lib='adv-parts')
    s.path(pvdd, (pvdd[0], 91.44)); s.power('PVDD', pvdd[0], 91.44, lib='adv-parts')
    s.path(mvdd, (mvdd[0], 99.06), (220.98, 99.06)); s.power('+1V8D', 220.98, 99.06, lib='adv-parts')
    g1, g4, ep = U1.pin('1'), U1.pin('4'), U1.pin('33')
    yG = g1[1] + 2.54
    s.path(g1, (g1[0], yG), (ep[0], yG), ep)
    s.wire(g4, (g4[0], yG))
    s.wire((g4[0], yG), (g4[0], yG + 2.54)); s.power('GND', g4[0], yG + 2.54)

    # ---------------- digital side ----------------
    for nm, net in [('D0P', 'CSI_D0P'), ('D0N', 'CSI_D0N'), ('CLKP', 'CSI_CLKP'), ('CLKN', 'CSI_CLKN'),
                    ('SDATA', 'SDA'), ('SCLK', 'SCL'), ('ALSB', 'ALSB'), ('~{RESET}', '~{RESET}'), ('~{PWRDWN}', 'PWRDWN')]:
        p = UP(nm)
        s.wire(p, (p[0] + 7.62, p[1])); s.label(net, p[0] + 7.62, p[1], 0)
    for nm in ['INTRQ', 'GPO0', 'GPO1', 'GPO2']:
        s.nc(UP(nm))

    # ---------------- J1: Raspberry Pi camera FFC ----------------
    J1 = s.place('Connector_Generic:Conn_01x15', 'J1', 'RPi_CSI_15pin', 330.2, 127.0, 0, FP['FFC'], LCSC['FFC'],
                 'FFC 15 pos 1.0 mm bottom contact (Amphenol SFW15R-1STE1LF, same as Pi Camera Module)', extra={'MPN': 'SFW15R-1STE1LF'},
                 ref_pos=(327.66, 106.68, 'left'), val_pos=(327.66, 148.59, 'left'))
    nets = {2: 'CSI_D0N', 3: 'CSI_D0P', 8: 'CSI_CLKN', 9: 'CSI_CLKP', 11: 'CAM_GPIO', 13: 'SCL', 14: 'SDA'}
    for n in range(1, 16):
        p = J1.pin(n)
        if n in (1, 4, 7, 10):
            s.wire(p, (p[0] - 5.08, p[1])); s.power('GND', p[0] - 5.08, p[1], 270, val_pos=(p[0] - 9.53, p[1] - 0.635, 'right'))
        elif n == 15:
            s.wire(p, (p[0] - 5.08, p[1])); s.power('+3V3', p[0] - 5.08, p[1], 90, val_pos=(p[0] - 9.53, p[1] - 0.635, 'right'))
        elif n in nets:
            s.wire(p, (p[0] - 10.16, p[1])); s.label(nets[n], p[0] - 10.16, p[1], 180)
        else:
            s.nc(p)
    s.text('Pi 4 J3 (CAMERA) pinout, 1:1 with Camera Module v2.1:\n1 GND  2 D0N  3 D0P  4 GND  5 D1N(nc)  6 D1P(nc)  7 GND\n8 CLKN  9 CLKP  10 GND  11 CAM_GPIO  12 nc  13 SCL0  14 SDA0  15 3V3\nI2C on Pi 4 = GPIO44/45 (i2c_csi_dsi); pull-ups to 3V3 exist on the Pi.', 300.0, 165.1, 1.27)

    # ---------------- control: reset / pwrdwn / alsb / i2c pull-ups ----------------
    # RESET
    xR = 243.84
    R3 = s.place('Device:R', 'R3', '10k', xR, 55.88, 0, FP['R'], LCSC['R10k'], 'RESET pull-up')
    s.power('+3V3', xR, R3.pin(1)[1] - 2.54); s.wire((xR, R3.pin(1)[1] - 2.54), R3.pin(1))
    yRn = 62.23
    s.wire(R3.pin(2), (xR, yRn))
    C5 = s.place('Device:C', 'C5', '4.7uF', xR, 66.04, 0, FP['C0603'], LCSC['C4u7'], 'RESET RC, tau = 47 ms: low (<0.8 V) for 13 ms after 3V3 (>5 ms min), high (>2 V) at 44 ms')
    s.wire((xR, yRn), C5.pin(1)); s.power('GND', *C5.pin(2))
    s.wire((xR, yRn), (251.46, yRn)); s.label('~{RESET}', 251.46, yRn, 0)
    TP5 = s.place('Connector:TestPoint', 'TP5', 'nRESET', 236.22, 57.15, 0, FP['TP'], '', 'RESET test point', ref_pos=(234.95, 54.61, 'right'), val_pos=(234.95, 57.15, 'right'))
    s.wire(TP5.pin(1), (236.22, yRn)); s.wire((236.22, yRn), (xR, yRn))
    JP2 = s.place('Jumper:SolderJumper_2_Open', 'JP2', 'CAM_GPIO>RST', 266.7, yRn, 0, FP['JP'], '', 'Open by default: connects CAM_GPIO to RESET', ref_pos=(262.89, 59.69, 'left'), val_pos=(259.08, 66.04, 'left'))
    s.wire((251.46, yRn), JP2.pin(1))
    s.wire(JP2.pin(2), (274.32, yRn)); s.label('CAM_GPIO', 274.32, yRn, 0)
    # PWRDWN
    R4 = s.place('Device:R', 'R4', '10k', xR, 83.82, 0, FP['R'], LCSC['R10k'], 'PWRDWN pull-up (chip enabled by default)')
    s.power('+3V3', xR, R4.pin(1)[1] - 2.54); s.wire((xR, R4.pin(1)[1] - 2.54), R4.pin(1))
    yPn = 90.17
    s.wire(R4.pin(2), (xR, yPn)); s.wire((xR, yPn), (251.46, yPn)); s.label('PWRDWN', 251.46, yPn, 0)
    JP3 = s.place('Jumper:SolderJumper_2_Open', 'JP3', 'CAM_GPIO>PWRDWN', 266.7, yPn, 0, FP['JP'], '', 'Open by default: connects CAM_GPIO to PWRDWN', ref_pos=(262.89, 87.63, 'left'), val_pos=(257.81, 93.98, 'left'))
    s.wire((251.46, yPn), JP3.pin(1)); s.wire(JP3.pin(2), (274.32, yPn)); s.label('CAM_GPIO', 274.32, yPn, 0)
    # ALSB
    xA = 302.26
    R5 = s.place('Device:R', 'R5', '10k', xA, 55.88, 0, FP['R'], LCSC['R10k'], 'ALSB pull-up: I2C addr 0x21 (write 0x42) = overlay default')
    s.power('+3V3', xA, R5.pin(1)[1] - 2.54); s.wire((xA, R5.pin(1)[1] - 2.54), R5.pin(1))
    s.wire(R5.pin(2), (xA, yRn)); s.wire((xA, yRn), (309.88, yRn)); s.label('ALSB', 309.88, yRn, 0)
    JP1 = s.place('Jumper:SolderJumper_2_Open', 'JP1', 'ALSB>GND', xA, 68.58, 90, FP['JP'], '', 'Close for I2C addr 0x20 (needs dtoverlay addr=0x20)', ref_pos=(305.0, 67.31, 'left'), val_pos=(305.0, 69.85, 'left'))
    s.wire((xA, yRn), JP1.pin(2)); s.power('GND', *JP1.pin(1))
    # I2C pull-ups
    R6 = s.place('Device:R', 'R6', '4.7k', 325.12, 83.82, 0, FP['R'], LCSC['R4k7'], 'SDA pull-up (in parallel with Pi pull-up)')
    R7 = s.place('Device:R', 'R7', '4.7k', 345.44, 83.82, 0, FP['R'], LCSC['R4k7'], 'SCL pull-up (in parallel with Pi pull-up)')
    yT = R6.pin(1)[1] - 2.54
    s.path(R6.pin(1), (325.12, yT), (335.28, yT)); s.path((335.28, yT), (345.44, yT), R7.pin(1)); s.power('+3V3', 335.28, yT)
    s.path(R6.pin(2), (325.12, yPn), (332.74, yPn)); s.label('SDA', 332.74, yPn, 0)
    s.path(R7.pin(2), (345.44, yPn), (353.06, yPn)); s.label('SCL', 353.06, yPn, 0)
    s.text('Reset / power-down / address\nOverlay adv728x-m sets no reset/powerdown GPIO and does not enable cam1_reg,\nso RESET and PWRDWN are pulled up on board; JP2/JP3 optionally route CAM_GPIO (Pi pin 11).\nALSB=1 -> 7-bit addr 0x21 as in adv7282m-overlay.dts (reg = <0x21>). Close JP1 for 0x20.', 240.03, 44.45, 1.27)
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

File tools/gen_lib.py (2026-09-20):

"""Generate hw/lib/adv-parts.kicad_sym: ADV7280WBCPZ-M symbol and project power symbols."""
import os, sys, copy
sys.path.insert(0, os.path.dirname(__file__))
from kisexp import *

KSYM = '/usr/share/kicad/symbols'

def eff(size=1.27, hide=False, justify=None):
    e = S('effects', S('font', S('size', size, size)))
    if justify: e.append(S('justify', Sym(justify)))
    if hide: e.append(S('hide', Sym('yes')))
    return e

def prop(name, val, x=0, y=0, hide=False, justify=None):
    return S('property', name, val, S('at', x, y, 0), eff(hide=hide, justify=justify))

def pin(etype, num, name, x, y, ang, length=2.54):
    return S('pin', Sym(etype), Sym('line'), S('at', x, y, ang), S('length', length),
             S('name', name, eff()), S('number', num, eff()))

def adv7280m():
    name = 'ADV7280WBCPZ-M'
    L, R, T, B = -20.32, 20.32, 25.4, -25.4
    pins = []
    # left: analog
    left = [('17','AIN1'),('18','AIN2'),('22','AIN3'),('23','AIN4'),('24','AIN5'),('25','AIN6'),('26','AIN7'),('27','AIN8')]
    for i,(n,nm) in enumerate(left):
        pins.append(pin('passive', n, nm, L, 20.32 - 2.54*i, 0))
    pins.append(pin('passive', '19', 'VREFP', L, -2.54, 0))
    pins.append(pin('passive', '20', 'VREFN', L, -5.08, 0))
    pins.append(pin('passive', '14', 'XTALP', L, -10.16, 0))
    pins.append(pin('passive', '15', 'XTALN', L, -12.7, 0))
    # right: digital
    pins.append(pin('output', '9', 'D0P', R, 20.32, 180))
    pins.append(pin('output', '10', 'D0N', R, 17.78, 180))
    pins.append(pin('output', '11', 'CLKP', R, 15.24, 180))
    pins.append(pin('output', '12', 'CLKN', R, 12.7, 180))
    pins.append(pin('bidirectional', '30', 'SDATA', R, 7.62, 180))
    pins.append(pin('input', '31', 'SCLK', R, 5.08, 180))
    pins.append(pin('input', '29', 'ALSB', R, 2.54, 180))
    pins.append(pin('input', '28', '~{RESET}', R, -2.54, 180))
    pins.append(pin('input', '32', '~{PWRDWN}', R, -5.08, 180))
    pins.append(pin('output', '5', 'INTRQ', R, -10.16, 180))
    pins.append(pin('output', '8', 'GPO0', R, -12.7, 180))
    pins.append(pin('output', '7', 'GPO1', R, -15.24, 180))
    pins.append(pin('output', '6', 'GPO2', R, -17.78, 180))
    # top: supplies
    for n,nm,x in [('2','DVDDIO',-10.16),('3','DVDD',-5.08),('21','AVDD',0),('16','PVDD',5.08),('13','MVDD',10.16)]:
        pins.append(pin('power_in', n, nm, x, T, 270))
    # bottom: grounds
    pins.append(pin('power_in', '1', 'DGND', -5.08, B, 90))
    pins.append(pin('power_in', '4', 'DGND', 0, B, 90))
    pins.append(pin('passive', '33', 'EP', 5.08, B, 90))
    sym = S('symbol', name, S('exclude_from_sim', Sym('no')), S('in_bom', Sym('yes')), S('on_board', Sym('yes')),
            prop('Reference', 'U', -17.78, 24.13, justify='left'),
            prop('Value', name, 0, -27.94),
            prop('Footprint', 'Package_DFN_QFN:QFN-32-1EP_5x5mm_P0.5mm_EP3.6x3.6mm', 0, -30.48, hide=True),
            prop('Datasheet', 'https://www.analog.com/media/en/technical-documentation/data-sheets/ADV7280.pdf', 0, -33.02, hide=True),
            prop('Description', 'SDTV video decoder with MIPI CSI-2 output, LFCSP-32 5x5 mm (CP-32-12)', 0, -35.56, hide=True),
            S('property', 'ki_keywords', 'video decoder CVBS MIPI CSI-2', S('at', 0, 0, 0), eff(hide=True)),
            S('property', 'ki_fp_filters', 'QFN*1EP*5x5mm*P0.5mm*', S('at', 0, 0, 0), eff(hide=True)),
            S('symbol', name + '_0_1',
              S('rectangle', S('start', -17.78, 22.86), S('end', 17.78, -22.86),
                S('stroke', S('width', 0.254), S('type', Sym('default'))), S('fill', S('type', Sym('background'))))),
            S('symbol', name + '_1_1', *pins))
    return sym

def ths7314():
    """TI THS7314 3-channel SDTV video amplifier, SOIC-8 (SLOS513A: 1-3 CH IN, 4 VS+, 5 GND, 6-8 CH3/2/1 OUT)."""
    name = 'THS7314'
    pins = []
    for i, (n, nm) in enumerate([('1', 'CH1_IN'), ('2', 'CH2_IN'), ('3', 'CH3_IN')]):
        pins.append(pin('input', n, nm, -12.7, 7.62 - 7.62 * i, 0))
    for i, (n, nm) in enumerate([('8', 'CH1_OUT'), ('7', 'CH2_OUT'), ('6', 'CH3_OUT')]):
        pins.append(pin('output', n, nm, 12.7, 7.62 - 7.62 * i, 180))
    pins.append(pin('power_in', '4', 'VS+', 0, 12.7, 270))
    pins.append(pin('power_in', '5', 'GND', 0, -12.7, 90))
    sym = S('symbol', name, S('exclude_from_sim', Sym('no')), S('in_bom', Sym('yes')), S('on_board', Sym('yes')),
            prop('Reference', 'U', -10.16, 11.43, justify='left'),
            prop('Value', name, 0, -15.24),
            prop('Footprint', 'Package_SO:SOIC-8_3.9x4.9mm_P1.27mm', 0, -17.78, hide=True),
            prop('Datasheet', 'https://www.ti.com/lit/ds/symlink/ths7314.pdf', 0, -20.32, hide=True),
            prop('Description', '3-channel SDTV video amplifier, 6 dB, 5th-order 8.5 MHz LPF, sync-tip clamp, 3-5 V, SOIC-8', 0, -22.86, hide=True),
            S('property', 'ki_keywords', 'video amplifier buffer CVBS filter', S('at', 0, 0, 0), eff(hide=True)),
            S('property', 'ki_fp_filters', 'SOIC*3.9x4.9mm*P1.27mm*', S('at', 0, 0, 0), eff(hide=True)),
            S('symbol', name + '_0_1',
              S('rectangle', S('start', -10.16, 10.16), S('end', 10.16, -10.16),
                S('stroke', S('width', 0.254), S('type', Sym('default'))), S('fill', S('type', Sym('background'))))),
            S('symbol', name + '_1_1', *pins))
    return sym

def power_symbol(name, base='+1V8', desc=None):
    lib = load_lib(os.path.join(KSYM, 'power.kicad_sym'))
    s = copy.deepcopy(get_symbol(lib, base))
    s[1] = name
    for c in s:
        if isinstance(c, list) and c[0] == 'symbol':
            c[1] = name + c[1][len(base):]
        if isinstance(c, list) and c[0] == 'property':
            if c[1] == 'Value': c[2] = name
            if c[1] == 'Description' and desc: c[2] = desc
    return s

def build():
    root = S('kicad_symbol_lib', S('version', 20241209), S('generator', 'kicad_symbol_editor'), S('generator_version', '9.0'))
    root.append(adv7280m())
    root.append(ths7314())
    root.append(power_symbol('+1V8D', desc='1.8 V digital rail (DVDD, MVDD) from U2'))
    root.append(power_symbol('+1V8A', desc='1.8 V analog rail (AVDD) from U3'))
    root.append(power_symbol('PVDD', desc='1.8 V PLL rail, filtered from +1V8A'))
    return root

if __name__ == '__main__':
    out = os.path.join(os.path.dirname(__file__), '..', 'hw', 'lib', 'adv-parts.kicad_sym')
    with open(out, 'w', encoding='utf-8') as f:
        f.write(dump(build()) + '\n')
    print('wrote', out)

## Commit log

2026-09-20 Stage 0: source docs, Pi 4 CSI pinout, overlay analysis, requirements
    - ADV7280 datasheet Rev. A, UG-637 Rev. A, AN-1260 (archived analog.com originals)
    - Raspberry Pi 4 reduced schematics, Camera Module v2.1 schematic
    - adv728x-m / adv7282m overlays, adv7180 driver, Pi 4 DTS sources
    - docs/requirements.md: chip pinout, supplies, input network, crystal,
    MIPI, Pi 4 camera connector pinout, overlay expectations, PCB stack
    - docs/assumptions.md: open questions (ALSB level vs overlay address,
    RESET/PWRDWN strategy, LDO choice, FFC orientation)
    Claude-Session: https://claude.ai/code/session_017Xy941kmWX9XJsHmZMcZcK
2026-09-20 Stage 0: resolve open questions (ALSB, reset/pwrdwn, LDO, FFC connector), note chip stock
    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
2026-09-20 Stage 0: chip is hand-soldered by the owner; note BOM/stencil consequences
    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
2026-09-20 Stage 1: KiCad 9 schematic, custom symbol/footprints, BOM, ERC clean
    - tools/: s-expression tooling, symbol lib, footprint and schematic generators,
    netlist connectivity check
    - hw/: project, schematic (ERC 0 errors / 0 warnings), adv-parts lib
    (ADV7280WBCPZ-M symbol, SFW15R-1STE1LF / RCA PSG01546 / X1SON footprints)
    - docs/schematic.pdf, docs/bom.csv with LCSC numbers
    - docs/assumptions.md: stage 1 decisions (22+51 R termination, YXC 5032
    crystal, TPD1E10B06 ESD, RCA hand-soldered, VREF cap)
    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
    [adv7280m-csi2.kicad_sch, bom.csv]
2026-09-20 Stage 1: tidy connector power-symbol labels, add schematic PNG preview
    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
    [adv7280m-csi2.kicad_sch]
2026-09-20 Stage 2: 4-layer board, JLC04161H-7628 stackup, scripted placement, renders
    - tools/gen_pcb.py builds the board from the schematic netlist: outline
    42x32 mm, layers, net classes (MIPI/Power), placement table, silkscreen
    - FFC on the left edge (pin 1 top), CVBS RCA/SMA on the right edge,
    crystal and input network at the chip, LDOs bottom-left
    - local SMA footprint without off-board silk; RCA/FFC silk fixes
    - DRC: only unconnected items (routing is stage 3)
    - docs/render-top.png, docs/render-bottom.png, assumptions stage 2
    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
    [adv7280m-csi2.kicad_pcb, adv7280m-csi2.kicad_sch]
2026-09-20 Stage 3: routing (tools/route_pcb.py), zones, length-matched MIPI, DRC clean
    - MIPI pairs 0.18/0.15 mm on F.Cu, one crossover via pair per lane
    (connector pin order is inverted vs. the chip), skew <= 0.04 mm
    - In1 solid GND, In2 power polygons, PVDD on B.Cu, GND pours top/bottom
    - thermal-pad via array, per-pad GND vias, I2C/CAM_GPIO on B.Cu
    - project rules/netclasses written by tools/write_pro.py
    - DRC with schematic parity: 0 errors, 0 warnings, 0 unconnected
    - docs: renders, per-layer images, assumptions stage 3
    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
    [adv7280m-csi2.kicad_pcb]
2026-09-20 Remove SMA input connector (J3): RCA only; regenerate schematic, board, docs
    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
    [adv7280m-csi2.kicad_pcb, adv7280m-csi2.kicad_sch, bom.csv]
2026-09-20 Stage 4: Gerber/drill, JLCPCB BOM and CPL, README
    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
    [BOM_JLCPCB.csv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]
2026-09-20 Stage 5a: THS7314 buffer stage schematic (separable section), symbol, BOM, assumptions A5
    - adv-parts library: THS7314 symbol (SLOS513A pinout)
    - Schematic (A2, rev B): J4 screw terminal 5 V -> SS14 -> 22 uF -> ferrite -> THS7314 VS+;
    input header J5 with 75 R termination, ESD, 3 x 100 nF sync-tip-clamp coupling;
    outputs with 75 R back-termination: CH1 -> JP4 -> CVBS_IN (and J8 header), CH2/CH3 -> J6/J7
    - ERC 0, check_nets extended, docs/schematic.pdf, schematic-1.png, bom.csv regenerated
    - THS7314 datasheet added to docs/datasheets
    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
    [adv7280m-csi2.kicad_sch, bom.csv]
2026-09-20 Stage 5b: buffer section placement (42x55 board, breakaway slot with two tabs), RESET C5 4.7 uF, render script
    - gen_pcb.py: outline with 2 mm slot and 2.5 mm tabs, placement of THS7314 section, silkscreen, rev B
    - route_pcb.py: zones cover the whole outline
    - C5 1 uF -> 4.7 uF (tau 47 ms, RESET low >= 13 ms); UG-637 figure reference fixed
    - tools/render.sh regenerates docs/render-*.png and layer images
    - assumptions A5-5 decided, A5-9 added; docs updated
    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
    [adv7280m-csi2.kicad_pcb, adv7280m-csi2.kicad_sch, bom.csv]
2026-09-20 Stage 5c: route THS7314 buffer section, CVBS_IN link through the tab, GND stitching; MIPI return-path fix; DRC clean
    - route_pcb.py: buffer nets (input node, coupling caps, outputs, 5 V chain), 22 GND vias, In2 GND zone under the section
    - +3V3 In2 zone extended under the D0N crossover stub, +1V8D notched; GND return vias next to the D0N vias
    - DRC: 0 violations, 0 unconnected; renders and layer images regenerated
    - assumptions A5-10, A5-11
    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
    [adv7280m-csi2.kicad_pcb]
2026-09-20 Stage 5d: fab outputs with the buffer section (Gerber/drill, JLCPCB BOM+CPL), fab.sh/jlc_bom.py, README
    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
    [BOM_JLCPCB.csv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]
2026-09-20 docs/mech: enclosure dimensions, board outline DXF, fab-layer DXF, STEP
    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
    [board-outline.dxf, board-top-fab.dxf, board.step]
